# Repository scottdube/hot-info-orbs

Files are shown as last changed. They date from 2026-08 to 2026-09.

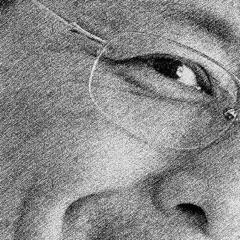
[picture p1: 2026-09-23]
test/fixtures/progressive.jpg

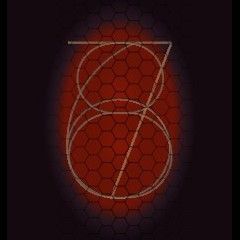
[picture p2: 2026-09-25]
images/ClockWidget/nixie.no-holes/colon_off.jpg

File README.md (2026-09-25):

# HoT Info Orbs

Five round 240×240 displays on one SPI bus, driven by an ESP32-S3 SuperMini, on
a custom carrier board. Clock, weather, stocks — and whatever else gets written.

Built as a club project, which shapes the whole thing: it is assembled by people
at a wide range of skill levels, so the build has to be hard to get wrong and
cheap to get into.

## Credit where it belongs

**This is a derivative of [Info Orbs by Brett Turner](https://github.com/brettdottech/info-orbs)**
— his project, his firmware, his idea. The upstream repository, its
[contributors](https://github.com/brettdottech/info-orbs/graphs/contributors),
and Brett's [assembly and flashing video](https://link.brett.tech/orbsYT) are
where this came from, and his boards can be
[bought as a dev kit](https://brett.tech/collections/electronics-projects/products/info-orbs-full-dev-kit)
if you want the original rather than our variant.

The firmware here is his, with local changes. The board is not: it is a new
design for a different microcontroller.

Licensed **AGPL-3.0**, inherited from upstream — see `LICENSE.txt`. Sharing a
built board with someone means they are entitled to the source, which is why
this repository is public.

## What is different here

| | Upstream | This |
|---|---|---|
| Microcontroller | ESP32 dev kit (30/38-pin) | **ESP32-S3 SuperMini** |
| Display supply | 3.3 V, off the module's regulator | **5 V, each module regulates its own** |
| API keys | compiled into `config.h`, shipped with live keys in the template | **`secrets.h`, gitignored, build fails without it** |
| Board | upstream's 2-layer design | **new carrier board, v1.1** |
| Firmware updates | USB cable every time | **over WiFi** — browser page or `pio run -e ota` |
| Boot splash | "Info Orbs by brett.tech", Brett's logo | **"HOT Info Orbs by HOT-Team"**, Yang's avatar for now; the Hands-On Tech hand (`images/hot-logo.jpg`) replaces it once Yang has this version |
| Settings | edit `config.h`, rebuild, reflash | **a page in the browser**: `http://<orb's IP>/settings` |
| Boot picture | fixed at build time | **upload your own** from the settings page |
| Weather | one Visual Crossing town | also **your own Tempest stations**, one page each (see SETUP step 10) |

**Upgrading a board flashed before 2026-09-23? Flash it once more over USB.**
The WiFi updates need a new flash layout (two firmware slots instead of one), and
only a USB flash writes that layout. Every update after that can go over WiFi:
open `http://<orb's IP>/update`, choose `.pio/build/esp32-s3-devkitc-1/firmware.bin`
and upload. The page also shows which commit is running. Set `OTA_PASSWORD` in
`secrets.h`, or anyone on your network can flash your orbs. Details in
[docs/SETUP.md](docs/SETUP.md#8-later-updates-no-cable-needed).

The 5 V change is the significant one. Upstream powers all five displays from
the ESP32 module's onboard regulator, which is why builders report the module
running at 82 °C with the radio off. The GC9A01 modules carry their own
regulators, so feeding them 5 V moves that load off the microcontroller
entirely. **Check the module you buy actually has one** — they vary, and it
looks like a small chip with capacitors either side on the back of the board.

## Getting started

**[docs/SETUP.md](docs/SETUP.md)** goes from an empty machine to a running orb,
assuming no PlatformIO experience, and ends in a troubleshooting table keyed by
the symptom you actually see.

The short version: copy **both** templates in `firmware/config/`, then build.

| Copy | To | Holds |
|---|---|---|
| `config.h.template` | `config.h` | preferences — timezone, units, tickers |
| `secrets.h.template` | `secrets.h` | your own API keys |

Both are gitignored; the templates are what's tracked. **The build refuses to
compile without both**, and refuses again if a key is left empty — deliberately,
because the alternative is a blank orb on the bench and no idea why.

Two free API keys are needed, about a minute each:
[Visual Crossing](https://www.visualcrossing.com/sign-up) for weather and
[TimeZoneDB](https://timezonedb.com/register) for DST changeovers. Register your
own — a shared key burns one free-tier quota and can be revoked out from under
everyone using it.

To have the orbs rotate Clock → Stocks → Weather on their own, set
`WIDGET_CYCLE_DELAY` in `config.h` to the number of seconds per page (15 works
well; 0 turns it off). Pressing a button restarts the countdown.

**After the first flash, most of `config.h` can be changed from a phone.** Open
`http://<orb's IP>/settings` to change the rotation time, tickers, weather
location and units, timezone, clock face and colors, night-dim hours,
upside-down mounting, and the start-up picture. The orbs restart to apply the
changes. The values in `config.h` become the defaults, and the page's reset button returns
to them. See [docs/SETUP.md](docs/SETUP.md#9-change-settings-from-a-browser).

## Hardware

The KiCad 10 project is in **[hardware/hot-info-orbs/](hardware/hot-info-orbs/)**.
Symbol and footprint libraries are project-local, so cloning and opening is all
that is required — nothing to install or copy into a global library.

**Board v1.1 — 10 boards ordered 2026-08-29**, tagged
[`v1.1-run1`](../../releases/tag/v1.1-run1). The exact gerbers sent to the fab
are committed at `hardware/hot-info-orbs/fab/`, and that file is never
regenerated: if a board comes back wrong, there has to be no question what was
sent. See [hardware/hot-info-orbs/fab/README.md](hardware/hot-info-orbs/fab/README.md)
for the order parameters and the drill-tool cross-check.

## Documentation

| | |
|---|---|
| [docs/SETUP.md](docs/SETUP.md) | empty machine to running orb |
| [docs/TRAPS.md](docs/TRAPS.md) | things that cost time once, so they cost it once |
| [docs/REQUIREMENTS.md](docs/REQUIREMENTS.md) | web control panel and OTA, with the traps that will bite whoever builds them |
| [docs/VARIANT-ESP32-S3-SUPERMINI.md](docs/VARIANT-ESP32-S3-SUPERMINI.md) | why the S3 SuperMini, including the arguments that reversed |
| [docs/ESPHOME-EVALUATION.md](docs/ESPHOME-EVALUATION.md) | why this is not an ESPHome project |

The variant and ESPHome documents keep the reasoning that changed rather than
only the conclusions. A decision with its argument attached can be revisited;
one without it gets re-litigated from scratch.

## Contributing

**Fork it and open a pull request.** Anyone can clone, build, fork and propose
changes — no permission needed for any of that, and a fork is yours to take in
whatever direction you like.

**Push access is by invitation**, and deliberately limited to a couple of
people. That is not gatekeeping the project, it is keeping the board files safe:
GitHub gives a personal repository no read-only collaborator tier, so adding
someone grants full write to everything including the KiCad files, which cannot
be merged if two people change them at once.

If you are building one of these and something is wrong or missing — a step in
the setup guide, a trap worth recording — [open an issue](../../issues) or send
a PR. Both are open to everybody, and a build that went sideways is worth
reporting even if you already worked around it: that is how the traps file gets
written.

## For collaborators

```bash
git pull --rebase     # before you start
# ...work...
git commit -am "what changed and why"
git push
```

`git config pull.rebase true` once, and a plain `git pull` does the right thing.

**KiCad files cannot be merged.** If two people edit `hot_info_orbs.kicad_pcb`,
git cannot reconcile them and somebody's work is lost. No tool fixes this, so it
is handled by saying so out loud: *"I've got the board"* / *"it's yours"*.
Everything else — firmware, docs, config — merges normally and needs no
ceremony.

Do not edit the KiCad project while it is open in KiCad, including with scripts.
KiCad holds its own copy in memory and writes it back on save, silently
discarding changes made underneath it. That has already cost a merge here once.

MegaLinter runs on every push and is configured **not** to commit anything back.
Upstream had it auto-committing fixes, which meant a bot pushed after every push
and rejected the next one — so "the remote has moved" stopped meaning "the other
person did something".

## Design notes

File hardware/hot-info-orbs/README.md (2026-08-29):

# HoT Info Orbs — KiCad project

ESP32-S3 SuperMini carrier for five GC9A01 displays. Original board by Yangmin
Shen, KiCad 10, received 2026-08-28.

## Libraries are project-local, on purpose

The custom symbols and footprints live in `lib/` and are wired up through
`sym-lib-table` and `fp-lib-table` using `${KIPRJMOD}`. **Do not move them into
your global KiCad libraries.** Clone the repo, open the project, and everything
resolves with no setup.

This is deliberate. Upstream's board (`PCBFiles+Schematics/Main PCB`) references
libraries named `A Local Libs` and `New folder` that exist only on its author's
machine — the footprints render because KiCad caches them inside the board file,
but nobody else can place a new instance or update one. Project-local tables
avoid that permanently.

| Nickname | Provides |
|---|---|
| `_AZDelivery components` | `GC9A01_TFT` symbol |
| `_ESP32 modules` | SuperMini symbol + footprint |
| `_Displays` | `GC9A01_PINS` footprint |
| `_Logos` | `Hot_Logo_5x5mm` footprint |

**`_Logos` was not in the zip.** It was recovered by extracting the embedded
footprint from `hot_info_orbs.kicad_pcb`, since KiCad caches full definitions in
the board file. It is byte-equivalent to what the board already places, but it
has not been round-tripped through the footprint editor — if it misbehaves, ask
Yang for the original.

`.kicad_prl` is deliberately not committed: it is per-user editor state
(open tabs, zoom, last-used layer) and only creates conflicts.

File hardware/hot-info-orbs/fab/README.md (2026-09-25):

# Fab package

## FIRST PRODUCTION RUN — v1.1

**ORDERED 2026-08-29 — 10 boards, JLCPCB.**

**`hot_info_orbs_v1.1_run1_gerbers.zip` is the package the first boards were
ordered from.** Generated 2026-08-29 from the board tagged `v1.1-run1`.

Do not regenerate this file to "refresh" it. If the board changes, the next run
gets its own zip and its own tag, and this one stays exactly as ordered — the
whole point is that when a board comes back, there is no question what was sent.

Verified before generating: ERC 0, DRC 0 unconnected pads, 0 schematic parity
issues. One silkscreen-overlap warning on B.Silkscreen near U2, accepted as
cosmetic.

Drill tools cross-checked against the footprint count:

| Tool | Holes | |
|---|---:|---|
| 0.30 mm | 18 | vias |
| 0.80 mm | 2 | C1 |
| 1.00 mm | 53 | 5×7 display headers + 18 module pins |
| 1.10 mm | 12 | 3 buttons × 4 pads |
| | **85** | total |

The four Ø3.20 mm mounting holes are deliberately absent from the drill file —
they are `Edge.Cuts` circles the fab routes, not drills.

### Via geometry — RESOLVED, no issue

Earlier drafts flagged the 0.6 mm / 0.3 mm vias as a possible problem: a
0.150 mm annular ring against a "0.18 mm minimum annular ring" figure on
JLCPCB's capabilities page. **That was the wrong number.**

JLCPCB's order form states the rule as a *diameter* difference, not a ring:

> "Via diameter should be 0.1mm (0.15mm preferred) larger than Via hole size."

For a 0.3 mm hole that means a 0.4 mm diameter minimum, 0.45 mm preferred. These
vias are **0.6 mm on a 0.3 mm hole — 0.3 mm larger, three times the minimum and
twice the preferred.** Not close to a limit.

The same tooltip also settles cost:

> "No additional charge when the via hole ≥0.3mm, and via diameter ≥0.4mm."

0.3 mm hole and 0.6 mm diameter meet both conditions, so there is no via
surcharge on this order.

**Lesson worth keeping:** the capabilities page and the order form express the
same constraint differently, and the capabilities page's figures are not
internally consistent. When a number decides something, take it from the order
form.

## Order parameters

| | |
|---|---|
| Layers | 2 |
| Dimensions | 198.8 × 28.5 mm |
| Thickness | 1.6 mm |
| Min quantity | 5 (price per board drops steeply above that) |

Board exceeds 100 × 100 mm, so it does not fall in the cheapest tier.

## What the drill file should contain

Cross-check after any regeneration — the counts come from the footprints, so a
mismatch means something was added or lost:

| Tool | Holes | |
|---|---:|---|
| 0.30 mm | 21 | vias |
| 0.80 mm | 2 | C1 |
| 1.00 mm | 53 | 5×7 display headers + 18 SuperMini pins |
| 1.10 mm | 12 | 3 buttons × 4 pads |

**The four mounting holes are deliberately not in the drill file.** They are
Ø3.20 mm circles on `Edge.Cuts`, so the fab routes them as cutouts rather than
drilling them. If they ever appear in the drill file, somebody converted them to
a footprint and that changes how they are made.

## Verified before generating

ERC 0, DRC 0, 0 unconnected pads, 0 schematic parity issues.

## Design rules

Set 2026-08-28 from JLCPCB's published capabilities for standard 2-layer, 1 oz.
They were all `0.0` before, so DRC was checking nothing.

| Rule | Value |
|---|---|
| Min clearance | 0.10 mm |
| Min track width | 0.10 mm |
| Min through-hole | 0.15 mm |
| Min via diameter | 0.25 mm |
| Min annular width | **0.15 mm — see below** |
| Min copper-to-edge | 0.5 mm (JLC allows 0.2; the board already passes at 0.5) |

The board uses 0.2 and 0.35 mm tracks, so it has 2–3.5× margin on width.

### The annular ring number is the one to confirm

JLCPCB's capabilities page states a minimum annular ring of 0.18 mm,
"recommended 0.25 mm or above". This board's 17 smaller vias are 0.6 mm pad on a
0.3 mm drill, giving **0.150 mm** — under that figure.

Two reasons it is set to 0.15 here rather than 0.18:

1. **The quoted 0.18 is not internally consistent** with the rest of that page,
   which also gives a 0.15 mm minimum drill and a 0.25 mm minimum via diameter —
   0.15 + 2×0.18 would be 0.51 mm, not 0.25. The figures appear to span
   different capability tiers, so 0.18 should not be treated as settled.
2. **0.6/0.3 is KiCad's default via** and is what an enormous number of boards
   are fabricated with at JLC every day.

**Enlarging the vias was tried and made things worse.** Taking the 17 vias to
0.8 mm gave the required ring but produced 24 clearance violations, because the
larger pads crowd neighboring copper. Fixing it properly means moving traces —
real layout work on someone else's board, not a settings change.

**If certainty is wanted before ordering, ask JLC directly whether 0.6/0.3 vias
are acceptable on a standard 2-layer order.** Nothing else on the board is close
to a limit.

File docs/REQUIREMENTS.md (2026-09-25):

# Feature requirements

Requirements for this build beyond what upstream provides. Each says what it
must do and *why*, because the why is what survives when the how changes.

Context: this is built as a learning project by people at a range of skill
levels, several of whom will be new to embedded development. **Complexity and
cost are constraints, not preferences.** A feature that adds a build step, a
part, or a failure mode has to earn it.

---

## R1 — Web control panel

**Settings must be changeable without rebuilding or reflashing the firmware.**

Today every preference lives in `config.h` and is compiled in. Changing a stock
ticker, a weather location, or a timezone means opening VS Code, editing a C
header, rebuilding, and connecting a USB cable. For someone who assembled the
hardware but does not write code, that is a wall.

**Must:**
- Serve a configuration page from the device over the local network
- Cover the settings people actually change: timezone, weather location, units,
  ticker list, clock face, and the scheduled dim hours (see the note below —
  this is not brightness control)
- Persist to NVS so settings survive a reboot and a firmware update
- Be reachable without special software — a browser on a phone is enough

**Should:**
- Show the device's current state: WiFi signal, uptime, last successful API call
- Allow API keys to be entered here rather than compiled in

**Interaction with the secrets work — read this before implementing.** Keys are
currently compile-time constants in a gitignored `secrets.h`, guarded so an
empty key fails the build. Moving keys to runtime NVS storage weakens that
guarantee: a device can then be flashed and running with no keys at all, failing
silently at the first API call. If keys move to the panel, the panel must show
their status plainly — set, unset, or last call failed — because the build-time
error that currently catches this goes away.

**There is no brightness control, and there cannot be on this hardware.** The
7-pin GC9A01 modules do not break out the backlight pin — BL is tied on at the
module, so the backlight runs at full output whenever the board is powered.
Upstream's "dimming" is a firmware effect: during the configured hours it
scales every color's R, G and B down before drawing (`Utils::rgb565dim`,
level 128 of 255 by default), so the display *looks* dimmer. It draws exactly the same
current.

So the panel can expose the dim *hours*, and must not offer a brightness slider.
A slider that does nothing is worse than no slider — someone will report the
orbs as too bright at night and be told to adjust a control that was never
connected to anything.

Real dimming needs different hardware: a display module that exposes BL, wired
to a PWM-capable GPIO. Worth weighing when the next batch of modules is chosen,
because it also cuts the dominant continuous load — the backlight, not the
radio, is what makes these boards warm.

**Screens off (added 2026-09-24).** A second schedule, separate from the dim
hours, sends the GC9A01's display-off and sleep-in commands (0x28, 0x10) to all
five panels. Each schedule has its own switch, so an orb can dim in the evening
and go off at bedtime, or use only one. Where the two overlap, off wins. The
HOT meeting that day asked for it, and the controller datasheet lists the
commands. Scott's first look in daylight: "looks pretty good". **Checked by
eye 2026-09-25:** the backlight stays on, so the panels glow with no content,
"not black by any stretch". Dim hours also checked and work. That fits the
LEDPWM result below: the LED runs off VCC on the module, not the controller.
So this "blanks the panels"; it does not turn the backlight off, and it
probably still draws full backlight current. **Not yet measured:** the
current draw.

**The controller does have backlight control; whether our module uses it is
untested (found 2026-09-25).** The GalaxyCore GC9A01 datasheet (V1.0
Preliminary), chapter 6 "Command", lists everything raised at the HOT
meeting: 10h/11h sleep in/out, 12h partial, 13h normal, 20h/21h inversion,
28h/29h display off/on. There is no separate power-down or deep-standby
command; Sleep In (10h) is the lowest-power state ("DC/DC converter is
stopped, Internal oscillator is stopped, and panel scanning is stopped").
Display Off (28h) only blanks the output, "no change of contents of frame
memory". Section 5.10.3, though, has an **LEDPWM output pin** meant to drive
an external LED driver, with Write Display Brightness (51h, DBV 0-255 = PWM
duty) and Write CTRL Display (53h, bits BCTRL, DD, BL, where BL = 0 means
"completely turn off backlight circuit"). That only works if the module
maker routed LEDPWM to the backlight. On the 7-pin modules the backlight
appears to run straight off VCC, but nobody has tested it. **Test:** send 53h
with BL = 0, and separately 53h = 0x24 plus 51h = 0x00, then look in a dark
room. If the backlight goes out, both real screens-off and real dimming become
possible on this hardware, and the "no brightness control" rule above changes.

**Result 2026-09-25: not wired.** Scott sent each command to all five panels
through a temporary `/bltest` route: BL = 0 ("off"), 53h = 0x24 with 51h at
0x00, 0x80 and 0xFF. None changed the backlight; only the restart did
anything. A panel whose backlight hung off LEDPWM would have gone dark at "off"
and at 0%, whatever the room light, so this settles it for these 7-pin modules:
the "no brightness control" rule stands, and real dimming still needs a module
that brings out BL. The route was removed once answered.

**What real screens-off would take (written 2026-09-25, not built).** No
command can darken these modules (above), so turning the backlight off means
cutting power to the displays. Nothing here has been built or measured on a
prototype, so treat it as a design to try.

*The load.* The displays run on **5 V**, each through its own onboard
regulator. The whole orb measures 342 mA at 5 V, so the display share is less
than that. A switch rated about 1 A leaves margin for the surge at turn-on.

*The switch.* It goes on the **5 V feed to the displays only**, high side.
Two ways to build it:

| | Parts | Notes |
|---|---|---|
| Discrete | P-channel MOSFET (e.g. AO3401A) in the 5 V line, 10 kΩ gate to 5 V; N-channel MOSFET (e.g. 2N7002) pulling that gate to ground; 10 kΩ from the 2N7002 gate to 3.3 V | The 2N7002 is needed because a 3.3 V pin cannot turn off a P-FET whose source is at 5 V. With the pull-up on the 2N7002, the displays are **on** by default, during boot and on firmware that knows nothing about the switch. The firmware drives the pin low to turn them off. |
| Load-switch chip | One IC rated to 5.5 V with a logic-level enable and controlled turn-on (TI TPS22918 is one; check the datasheet before choosing) | One part instead of three, and it ramps on gently. That matters because the ESP32's regulator is fed from the same 5 V line, and a hard switch-on dip could reset it. Needs a pull-up on the enable pin for the same displays-on default. |

*The pin.* The firmware already uses GPIO 1, 2 and 4–15. The vendor pinout
lists 16, 17, 18 and 21 as broken out and safe to use, but nobody has checked
them on the board we have. Look on the back pads before designing around one.
Avoid the strapping pins (0, 3, 45, 46). GPIO 14 is taken: it's the dummy
chip-select that TFT_eSPI still toggles. GPIO 15 is taken too: it's the
activity-light output (`BUSY_PIN`).

*Firmware, in order:*
1. **Off:** stop SPI, then drive MOSI, SCLK, DC, RST and all five CS lines
   **low**, then switch the power off. If those lines stay high, current leaks
   into the unpowered display chips through their input pins. That half-powers
   them and can make the backlight glow faintly, which defeats the point.
2. **On:** switch the power on, wait for the module regulators (start with
   50 ms and measure), restart SPI, re-initialize all five panels (power loss
   wipes the controller), then redraw everything. The existing screens-off
   schedule and 60-second button wake stay as they are; only what "off" does
   changes.

*Checks once built:* the orb's current at 5 V with screens off against on
(the saving we'd be buying); a meter on one module's VCC while off, which
should read about 0 V (a volt or two means a line is still high); and a
dark-room look.

*Rejected:*
- Switching the ground side. A logic-level N-FET is simpler to drive, but
  with ground cut, the modules find ground through the signal lines.
- Pulsing the supply rapidly on and off (PWM) to dim. It resets the display
  controller every cycle.
- The controller's LEDPWM pin. It isn't wired on these modules (tested above).

Dimming for real would need the LED switched on its own, which means modifying
each module. A look at the back of one would show whether there's a transistor
or pad to tap.

*Cost against the project's constraints:* three small parts or one IC, one
pin, and firmware sequencing. Worth it on a new carrier board. As a fix for
one existing orb, it's a lot of work.

**Security floor:** the panel holds WiFi credentials and API keys. It needs at
minimum a password, and it must never display stored secrets back in plaintext.
An unauthenticated page on the LAN that reveals WiFi credentials is not
acceptable, however friendly the network.

**Upstream already built this — found 2026-09-23.** `upstream/dev` (not
`main`, which this fork is based on; 571 commits apart) has
`firmware/src/core/configmanager/ConfigManager.*`: a settings page on
WiFiManager, stored in NVS via `Preferences`, with sections, an "advanced"
toggle and i18n. Per-widget settings register themselves; MainHelper.cpp
covers timezone, language, widget cycle delay, NTP server, orb rotation, and dim
hours. Measured by building `upstream/dev` against our S3 board and
partitions.csv: **1,712,081 bytes, 87.1% of one OTA slot**, no OTA code yet. So it
fits. Two conflicts with decisions here: it offers a `tftBrightness` setting,
which does nothing on these displays (see above), and its key handling has to
be reconciled with the `secrets.h` split.

**Status 2026-09-23: partly implemented — our own page, not upstream's.**
`http://<orb>/settings` covers rotation time, tickers, weather location,
units and screen mode, timezone, 12/24 h, AM/PM, starting clock face, clock
and shadow colors, night-dim hours, upside-down mounting, and an uploadable
boot picture. It saves to NVS and restarts. It has no brightness control.
It uses the same password as `/update`, and holds no secrets.
Tested from a phone on 2026-09-23: a 310×372 transparent PNG went through the
page's crop-and-shrink and arrived as a 16.7 KB baseline 240×240 JPEG, which the
orb stored and serves back. Not yet checked by eye on the displays.
Design and reasons: `docs/superpowers/specs/2026-09-23-web-settings-design.md`.
Tempest support (built 2026-09-24, merged to main 2026-09-25) adds Tempest station IDs and labels to the
page, each with its last fetch result (✔/✖, age, duration, error): the
per-source status the note above asks for. The Tempest token is deliberately
**not** on the page; it stays in `secrets.h`.
Not done yet: API keys on the page (needs the per-key status above first),
last-API-call status, and enabling/disabling widgets. WiFi signal, access
point and channel were added 2026-09-25, along with roaming (below). Flash is
87.0% of a slot, and the stop line is 92%.

**WiFi roaming (added 2026-09-25).** An orb moved across a building kept its
far access point: 341 ms average ping and 5% loss, while the router answered
in 3 ms, and every 96 KB Tempest reply arrived cut short. Restarting didn't
help. The ESP32's default connect takes the first AP it hears, not the
strongest, and it never moves until the link dies. Now it scans every channel
and joins the strongest at connect. While connected, it checks 20 s after
joining and every 2 minutes after that. If the signal is below -65 dBm, it
scans in the background and moves to an AP at least 8 dB stronger on the same
network. The margin keeps two similar APs from trading the orb back and forth.
If the new AP doesn't take it within 20 s, it rejoins by network name.
Decision logic: `firmware/src/core/wifi/RoamPolicy.h`, tested on the host.
Rejected: the router steering clients (UniFi "lock to AP" is a per-device
setting someone has to know to change, and not every owner runs UniFi), and
802.11k/v/r roaming (it needs router support and ESP-IDF config this build
doesn't expose).

## R2 — Over-the-air firmware updates

**Firmware updates must not require a USB cable.**

**Status 2026-09-23: implemented and tested on the SuperMini.** USB flash of the
new layout, then a browser-style multipart upload to `/update` by IP: 11 s
upload, back on the network 14 s later. otadata read back over USB afterwards:
highest sequence 2 → running `app1`, state `VALID`, i.e. the new image reached
WiFi and confirmed itself. Not yet exercised: `pio run -e ota` (espota), a
password, an interrupted upload, and an actual rollback.
`firmware/src/core/ota/OtaUpdater.*`, browser upload at `/update` plus
ArduinoOTA (`pio run -e ota -t upload`). Partition table reworked to two
1.875 MB slots (app at 83.4%) with the filesystem cut to 128 KB. A new image is
confirmed only after it reaches WiFi and starts listening for the next update,
using the core's `verifyRollbackLater()` hook; the prebuilt bootloader has
rollback enabled. Version shows on the boot screen and the update page. Still
open: the *Should* — devices do not check for updates themselves.

The orbs sit on a desk or shelf, often in a case. Fixing a bug currently means
retrieving the device, opening it if necessary, finding a data-capable USB
cable, and running a toolchain the owner may not have installed. In practice
that means fixes do not reach people.

**Must:**
- Accept a firmware image over the network and apply it
- Fall back safely on a failed or interrupted update — a half-written image
  must not brick the device
- Report the running firmware version somewhere visible

**Should:**
- Check for updates rather than requiring a push to each device

**Constraint worth checking early:** the current build occupies 77.2% of a 2 MB
app partition. Conventional OTA wants two app partitions so the old image
survives until the new one is verified. Two 2 MB partitions do not fit in 4 MB
alongside NVS and SPIFFS. **The partition table in `partitions.csv` will need
reworking, and that is a bigger change than it sounds** — it is worth confirming
the layout before building against the current one.

## Prior art

[JoeAWagner/orbital-orbs](https://github.com/JoeAWagner/orbital-orbs) — Info
Orbs firmware with a web control panel and OTA updates, written for the ESP32-S3
variant. Both requirements here, already implemented by someone else. Read it
before writing anything: it may be adoptable directly, and where it is not, it
will still show where the partition and NVS problems actually bite.

## Open question — ESPHome

Whether these requirements are better met by reimplementing on ESPHome rather
than extending the Arduino firmware. ESPHome provides OTA, a web server, and
`secrets.yaml` natively rather than as features to build. Evaluated separately;
see `docs/ESPHOME-EVALUATION.md`.

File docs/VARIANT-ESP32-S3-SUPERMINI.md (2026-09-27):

# Variant: ESP32-S3 SuperMini

Status: **REOPENED 2026-08-27.** Declined earlier the same day on cost and
complexity, then reopened at Yang's request. The power objection that drove the
original decline now looks resolvable — see [Reopened](#reopened) at the end.
The earlier decision record is kept below rather than deleted, because the
reasoning that reversed is the useful part. This records what the
switch would actually cost, so the decision is made against facts rather than
against how small the board looks.

Date: 2026-08-27

---

## The question

Replace the 30-pin ESP32 devkit with an ESP32-S3 SuperMini. Does it have enough
pins, and what does the change drag along with it?

**Short answer: pins are not the problem. The carrier board is.**

---

## 1. Pin budget — it fits, barely

Counted from `firmware/config/config.h.template`, not estimated:

| Function | Pins | Notes |
|---|---:|---|
| SPI MOSI + SCLK | 2 | `TFT_MISO` is `-1`; displays are write-only |
| Display DC + RST | 2 | shared across all five |
| Per-screen chip select | 5 | one per display, the unavoidable cost of 5 panels on one bus |
| Buttons | 3 | |
| **Hard requirement** | **12** | |

Two more are soft. `BUSY_PIN` is a real output (`Widget.cpp:7`) but only drives an
activity indicator and can be dropped. `TFT_CS` appears solely in a
`Serial.println` in `ScreenManager.cpp:28` — very likely reclaimable, but confirm
TFT_eSPI isn't consuming it internally before counting on that.

**Against the candidates:**

| Board | Usable GPIO | Verdict |
|---|---|---|
| ESP32-C3 SuperMini | ~11 | **Does not fit.** Short before the optional pins. |
| ESP32-S3 SuperMini | 32 broken out; conservative "safe" set is IO1, IO2, IO4–8, IO15–18, IO21 = **exactly 12** | Fits, with zero margin on the safe set |

The safe set landing on exactly 12 is worth sitting with. It works, but any
future addition — a rotary encoder, a light sensor, an I²C bus — means reasoning
about strapping and boot-state pins rather than picking a free one.

**Unverified:** the S3 SuperMini pin classification above is from vendor
documentation, not from the board on the shelf. The specific AITRIP unit's flash
size and whether it carries PSRAM are **not confirmed**. Both must be read off
the actual module before any footprint is drawn.

## 2. Retracting the flash-size argument

An earlier claim that the S3's 4MB flash relieves the current squeeze **is
wrong**, and the correction matters because it removes one of the two upsides.

`partitions.csv` already maps a 4MB device:

```
app0,     app,  ota_0,   0x10000, 0x200000     <- 2MB app partition
spiffs,   data, spiffs,  0x210000,0x1E0000
```

The build reports 77.2% of `0x200000`. That is a **partition layout** constraint,
not a chip constraint. The classic board already has 4MB. An S3 SuperMini with
4MB therefore gives nothing here — and if the app partition needs to grow, that
can be done on the existing hardware by editing this file, no board change.

What genuinely remains on the S3 side: native USB (less fiddly flashing, no
BOOT-button dance), more GPIO headroom in principle, and physical size.

## 3. The carrier board — reassessed for 2-layer

**Updated 2026-08-27: two-layer boards are available.** This reverses most of
what this section originally argued. Recorded rather than deleted, because the
reversal is the useful part.

### What the original argument was

Read from `PCBFiles+Schematics/Main PCB/info_orbs.kicad_pro` and `.kicad_pcb`:

- Upstream's board is **2-layer**, track width defaults `[0.0, 0.2, 0.6]` mm
- In-house milling is **single-sided, no plated vias, 0.4 mm floor**

So upstream's board could not be milled here, and any board — SuperMini or
devkit — meant a single-sided redesign with jumpers. That made the SuperMini's
PCB cost look nearly free, since a redesign was happening anyway, and it made
ordering look attractive purely to escape the one-layer fan-out problem.

### What changes with 2 layers on the table

Every one of those premises drops:

| | Was (single-sided milled) | Now (2-layer ordered) |
|---|---|---|
| Five CS lines crossing a shared bus | jumper exercise, real routing risk | trivial, vias handle it |
| Min track / clearance | 0.4 mm floor | ~0.15 mm |
| Upstream's existing board | unusable | **usable as-is, or as a starting point** |
| Turnaround | hours | weeks |

**The important consequence: upstream's PCB becomes an asset instead of a dead
end.** For the classic devkit it can be ordered as drawn — zero PCB work. For
the SuperMini, the display and button sections of the existing KiCad project are
reusable; only the module footprint and its fan-out need redrawing.

### Which means the SuperMini's cost went back up

Not to "from scratch", but no longer to "free". Honestly stated:

- **Classic devkit, ordered:** no PCB work at all. Send upstream's Gerbers.
- **SuperMini, ordered:** new module footprint, re-layout of the module area and
  its fan-out, then a full verification pass. Days, not weeks — but not zero,
  and it is work that buys size and native USB rather than function.

The single-sided constraint was doing a lot of the arguing in favor of the
SuperMini. With it gone, the case rests on what it was always really about:
physical size and nicer flashing.

### The new cost is schedule

Ordered boards run weeks, not hours. That is the constraint to plan around now —
and it argues for settling the pin map on flying leads first, because a mistake
discovered after ordering costs another full turnaround.

## 4. Constraints on the carrier

**Applies only if this is milled in-house.** For an ordered 2-layer board the
drill-snapping and annular-ring gates below are irrelevant — the fab plates the
holes and stock KiCad footprints are fine. Kept because the milled path is still
open, and because the socket-pad trap is easy to carry into the wrong context.

Values traced to source, not quoted from memory:

| Constraint | Value | Source |
|---|---|---|
| Annular ring minimum | **0.25 mm**, checked *after* drill snapping | `pcbmill/constants.py:45`, `toollib.py:156` |
| Owned drill bits | 0.032″ / 0.0465″ / 0.0625″ / 0.125″ (0.813 / 1.181 / 1.588 / 3.175 mm) | `pcbmill/toollib.py:24-31` |
| Drill snapping | to **nearest** owned bit, not up | `toollib.py:128-138` |

Consequences for this board specifically:

- **Socket rows need 1.78 mm pads, not KiCad's stock 1.70 mm.** The stock
  `PinSocket_1x15_P2.54mm_Vertical` clears the 0.25 mm gate by about 9 microns.
  That is not margin. If the SuperMini is socketed rather than soldered down,
  this applies to every pin in both rows.
- **Machined-pin (turned) sockets, or direct-solder the module.** Never stamped
  female headers — a defective one cost a full day in this shop and mimicked a
  dead flash chip perfectly.
**True on any board, milled or ordered:**

- **Antenna keepout** at the SuperMini's antenna end. Non-negotiable, and easy
  to forget on a board this small where every mm is contested.
- **Bulk cap near the module supply pin** — 220 µF electrolytic plus 0.1 µF
  ceramic, ceramic closest. Five displays plus WiFi transmit bursts is exactly
  the load that browns out a module fed by a long trace.
- **Flash/PSRAM pin keepouts must be re-derived for the S3.** The familiar
  "GPIO6–11 are the flash bus" rule is an **ESP32-classic** fact and does not
  transfer. Whichever pins this variant reserves need NPTH mechanical holes —
  hole, no pad — so the pins pass through touching nothing.

## 5. Mounting — unanswered, and it blocks layout

**How does the board physically mount inside the orbs assembly?** Standoffs,
panel screws, or floating on the display connectors? This is not yet known, and
a board has reached Gerber export in this shop with no mounting holes because
nobody asked.

On the mill, mounting holes are free — same op, same G54. Retrofitting means
hand-drilling a soldered, masked board next to a pour, with no registration.
Decide before placing the first component. Default is M3 drilled 3.175 mm, NPTH,
with a ~6.5 mm keepout and center ≥ 3.2 mm from the board edge.

## 6. Power — the regulator is the real constraint

> **Superseded for the current build (noted 2026-09-25).** The displays now
> run on **5 V**, each through its own onboard regulator, so the SuperMini's
> regulator carries only the ESP32 (see `docs/features.html`: 342 mA / 1.71 W
> for the whole orb at 5 V, measured). The netlist analysis below describes
> the upstream wiring, and it is kept for the reasoning. Its load figures are
> estimates that the measurement replaces.

**Correction:** an earlier draft of this section said the displays run off 5 V.
They do not. The netlist is explicit — display connector pin 7 is
`Net-(U1-3.3v)` and pin 6 is GND. All five displays hang off the **module's
onboard 3.3 V regulator**, which makes the regulator comparison decisive rather
than incidental.

| | DevKit V1 (DOIT) | S3 SuperMini |
|---|---|---|
| Regulator | AMS1117-3.3, SOT-223 | ME6211-series, SOT-23-5 |
| Datasheet max | 1 A | 500 mA |
| Practical sustained | ~500-600 mA before thermal droop | 500 mA, and needs >=4.3 V in |

**The SuperMini has about half the headroom in a much smaller package.**

Estimated load, not measured: a GC9A01 1.28in module draws roughly 40-80 mA at
3.3 V with the backlight up. Five is 200-400 mA. The ESP32 itself spikes to
350-500 mA on WiFi transmit. Peak lands near **550-900 mA** — marginal on the
AMS1117, over the limit on a 500 mA part.

**Two things to verify physically, both quick:**

1. **Read the regulator marking** on one of the AITRIP boards. The ME6211 is
   documented on the C3 SuperMini and the S3 shares the SOT-23-5 footprint, but
   this specific board is unconfirmed.
2. **Measure one GC9A01 at full brightness** (part #70 is on the shelf) and
   multiply by five. That replaces the whole estimated range with a number.

### The design answer that removes the question

Give the display rail **its own 3.3 V regulator** on the carrier board, fed from
the 5 V input, rather than hanging five displays off the module's LDO. A 1 A LDO
is about a dollar, and the board then does not care which module is fitted.

Since a new board is being drawn anyway, this is likely correct regardless of
how the SuperMini decision goes — and it retires the single biggest electrical
risk in the variant.

## 7. Firmware port

Lower risk than the hardware, but not free:

- New PlatformIO environment (S3 target, not `esp32doit-devkit-v1`)
- Pin map rewrite in `config.h.template` — and the pin numbers become part of
  the variant's identity, so the two builds can no longer share one config
- TFT_eSPI on S3 needs its own verification pass; the GC9A01 driver is the same
  but the SPI peripheral is not
- `platformio.ini` currently declares `platform = espressif32` unpinned, which
  is a separate reproducibility question that a second board makes worse

## 8. Cost that is not technical

Upstream's assembly video, wiring diagram and dev kit all assume the classic
board. Anyone following those with a SuperMini in hand gets stuck. If more than
one person is building these, a board change means the written setup path in
`docs/SETUP.md` forks — or stops matching reality for half the builders.

---

## What is on the shelf

- **AITRIP Type-C SuperMini ESP32-S3** — InvenTree part #60, 4 on hand: 2 at
  B3-R6C3 (SLN), 2 at LRD. Recorded as spare stock, bought for the voice
  assistant and wrong for it. Flash/PSRAM variant **not verified**.
- Classic devkits: #62 (ESP-WROOM-32, 2 free at B3-R6C3) and #58 (38-pin CP2102,
  2 free). The current build BO-0016 allocates one of #62.

## Recommended sequence, if this proceeds

Ordered so the cheapest disqualifier runs first:

1. **Measure the 5 V draw** of five displays at full brightness. Five minutes,
   and it can end the discussion.
2. **Verify the actual module** — read the silk, confirm the flash/PSRAM variant
   and the true usable-GPIO set. "SuperMini" is not a specification.
3. **Port the firmware on flying leads.** Prove the S3 drives five GC9A01s
   before any copper is drawn. No PCB risk taken until this works.
4. **Lay out the carrier** as a modification of upstream's KiCad project, not
   from scratch — the display and button sections carry over.

Ordering runs weeks per turn, so steps 1-3 are not optional preliminaries. A pin
map error found after the boards arrive costs another full turnaround.

Steps 1–3 cost parts already on the shelf and no money. Step 4 is where the
commitment starts.

## Open questions

- How does the board mount in the assembly? (blocks layout — see §5)
- ~~Milled single-sided, or ordered 2-layer?~~ **Resolved 2026-08-27: 2 layers
  available.** See §3 for what that reversed.
- Does the variant replace the classic build or sit alongside it? That decides
  whether `config.h.template` forks or grows conditionals.
- Is the SuperMini socketed or soldered down? Socketing is friendlier to
  reflashing and rework but drags in the 1.78 mm pad requirement and doubles the
  height.

---

# Appendix: Is upstream's board poorly laid out?

Measured 2026-08-27 from `PCBFiles+Schematics/Main PCB/info_orbs.kicad_pcb`.
Every number here came from parsing that file, not from inspection by eye.

## What is on the board

| | |
|---|---|
| Footprints | 16 (3 are graphics with no pads) |
| Pads | 135, **all through-hole**, no SMD |
| Nets | 36 |
| Track segments | 277 — 155 on F.Cu, 122 on B.Cu |
| Copper length | 204 cm front, 38 cm back |
| Vias | 56, every one 0.6 mm pad / 0.3 mm drill |
| **Copper pours** | **zero** |

## Three findings that explain the 56 vias

**1. There is no ground plane.** Not on either layer. Every ground and power
connection is an individually routed trace. Ground touches 14 pads across the
board and is the highest-fanout net on it; a bottom-layer pour would absorb
nearly all of those with no vias at all. The 14-via net `Net-(J1-Pin_1)` is
ground, stitched across the board one hop at a time.

**2. The board carries TWO ESP32 module footprints, both fully wired.** `V1`
(`New folder:38 Pin Board`) and `V2` (`A Local Libs:38 Pin Board thin`) — 38
pads and 36 nets each, connected in parallel so either module variant can be
fitted. That is a deliberate choice, not an error, but it roughly doubles the
routing burden. Every shared bus net reaches seven pads instead of five: five
displays plus both module positions.

**3. The back layer is used for stubs, not for a strategy.** 204 cm of copper on
the front against 38 cm on the back, yet 56 vias to service that back layer.
122 back-layer segments carrying 38 cm total means the pattern is hop over an
obstacle and hop straight back.

Supporting evidence of hurry rather than intent: two *different* 38-pin board
footprints, a library named `New folder`, a footprint named `Untitled`, and no
power symbols in the schematic — the nets are auto-named `Net-(U1-3.3v)` and
`Net-(J1-Pin_1)` rather than `+3V3` and `GND`, which is *why* nothing could be
poured. You cannot pour to a net the schematic never named.

None of this makes the board wrong. It works, and hundreds of people have built
it. It was drawn for a fab house where vias are free and there is no reason to
count them.

## How many connections actually need the other side?

Tested rather than estimated: the netlist was built into a graph — one node per
pad, net connections as edges, each component's pin rows locked into their
physical order, routing under through-hole parts allowed — and checked for
planarity. A planar graph can be drawn with no edge crossings, which is the
graph-theory statement of "routable on one layer".

| Scenario | Net edges | Planar? | Crossings required |
|---|---:|---|---:|
| One module, nothing poured | 59 | **yes** | **0** |
| One module, GND poured | 49 | **yes** | **0** |
| One module, GND + 3V3 poured | 37 | **yes** | **0** |

**The circuit is inherently single-layer routable.** Upstream's 56 vias are a
property of their layout, not of this design. Drop the duplicate module
footprint, pour ground, and place the five display connectors in a row so the
shared bus runs along it, and the topology has no forced crossings at all.

### What this result does not prove

Planarity is about topology; it ignores geometry. Specifically:

- It assumes traces can be made as thin as needed. At the 0.4 mm milling floor
  they cannot.
- **It ignores that you cannot thread a trace between 0.1″ header pads.** The
  gap between 1.7 mm pads at 2.54 mm pitch is about 0.84 mm — too tight to
  isolate reliably on the mill. With 5×7-pin connectors, routing *around* rather
  than *between* is where real crossings will appear.
- Display placement is not actually free; the enclosure dictates where five orbs
  sit.

So the honest reading: **zero crossings are forced by the circuit, and whatever
crossings appear will be driven by clearance geometry, not topology.** That is a
much better starting position than 56 suggests, and it means a small number of
jumpers, not a stitched board.

## Consequence: a milled prototype looks feasible after all

This retracts the earlier claim in §3 that a single-layer version would be a
jumper exercise. It would not. A single-sided milled board with a ground pour
and a handful of jumpers is a realistic prototype path, which matters because
production is going to JLCPCB regardless — the mill only has to get a testable
board onto the bench, not produce the final article.

The remaining unknown is geometric, not topological, and the way to settle it is
to attempt the layout rather than to reason further about it.

---

# Appendix B: Attempting the layout — where geometry actually bites

The planarity result in Appendix A says zero crossings are forced by the
circuit. Planarity ignores geometry. This is what happens when the geometry is
put back in.

## The pinout is the whole problem

All five display connectors are identical 1x7 headers:

| Pin | Net | |
|---|---|---|
| 1 | IO18 — RST | shared by all five |
| **2** | **IO13 / IO33 / IO32 / IO25 / IO21** | **unique per display** |
| 3 | IO19 — DC | shared |
| 4 | IO17 — MOSI | shared |
| 5 | IO23 — SCLK | shared |
| 6 | GND | shared |
| 7 | 3V3 | shared |

**The one signal that differs per display sits at pin 2 — fenced in between two
shared bus lanes.** Every other pin can be served by a straight lane running the
length of the row. Pin 2 cannot, because each connector's pin 2 goes somewhere
different.

## The hard constraint, computed

Header pads are 1.70 mm on 2.54 mm pitch:

```
pad-to-pad gap    0.84 mm
one track needs   1.20 mm   (0.40 trace + 0.40 clearance each side)
tracks that fit   0
```

**Nothing routes between adjacent header pads at the milling floor.** Not one
track. Every connection either arrives from outside the pin column or does not
arrive.

## The layout that follows

Place the five connectors in a row, pin columns parallel, pins perpendicular to
the row. Then:

- **Pins 1, 3, 4, 5, 7 become straight horizontal lanes**, each at its own pin
  height, hopping connector to connector. No crossings, no detours.
- **Pin 6 (GND) disappears into the pour** and costs nothing.
- **Pin 2 is the exception.** Each CS line must reach a pad whose neighbors on
  both sides are occupied bus lanes.

A CS line heading for a distant connector must route around the intervening pin
columns — there is no path between the pads. Sending it above the row (past pin
1) into a clear channel works, and 4 such tracks need only 3.6 mm of channel,
which is nothing on a board this size. But coming back *down* to pin 2 means
crossing the pin-1 RST lane.

**That crossing is the irreducible cost, and it is one per CS line that has to
get past another connector.**

## The number

| Module placement | Jumpers |
|---|---:|
| Module at one end of the row | **4** |
| Module in the middle of the row | **3** |

With the module at the left, CS for the nearest display runs alongside the RST
lane without crossing it; the other four each cross once. Moving the module into
the middle of the row splits the fan-out in both directions and saves one.

Routing the RST lane above the CS channel instead does not help — then RST has
to come down to each pin 1 and crosses the CS tracks instead. The count is
symmetric because the topology is.

## Verdict

**Three or four jumper wires on a single-sided milled board.** Not 56, not
zero. That is an entirely reasonable prototype — a handful of short wire links
soldered on the copper face.

The path is open: mill a single-sided prototype in-house with a GND pour and
3–4 jumpers, prove the firmware and the pin map on real hardware, then send the
proper 2-layer design to JLCPCB for production where the jumpers become vias and
cost nothing.

## One trap to fix before milling

The stock 1x7 header footprint is **1.70 mm pads on a 1.00 mm drill**. Milled:

```
drill 1.00 snaps to nearest owned bit 1.181 (UP)
annulus = (1.70 - 1.181)/2 = 0.2595 mm
gate = 0.25 mm  ->  passes by 9.5 microns
```

It passes, with no margin worth the name — this is exactly the socket-row case
the shop guide flags. **Grow the header pads to 1.78 mm** before generating CAM,
which takes the annulus to 0.299 mm and a 49 µm margin. Same change applies to
all five display connectors and the module row if it is socketed.

Note this is a *milling* concern only. Sent to JLCPCB, the holes are plated and
the stock footprint is fine.

---

# Appendix C: HackerBox 0129 "Orbital" — someone already built this

Found 2026-08-27. HackerBoxes shipped a monthly kit that is this exact variant:
ESP32-S3 SuperMini, five GC9A01 modules, three tactile buttons, custom PCB.
Their own description: *"originally inspired by the very cool Info Orbs from
Brett Turner... employs a different microcontroller (ESP32-S3 vs ESP32) and thus
has a different PCB layout and different IO pin assignments."*

Sources: [product page](https://hackerboxes.com/collections/past-hackerboxes/products/hackerbox-0129-orbital),
[build guide](https://www.instructables.com/HackerBox-0129-Orbital/) (published
2026-07-29, 11 people report building it).

## What this hands us for free

**A working pin map for the S3, published:**

```c
#define TFT_MOSI 11
#define TFT_MISO -1
#define TFT_SCLK 12
#define TFT_CS   10
#define TFT_DC    9
#define TFT_RST  13
#define USE_HSPI_PORT

#define SCREEN_1_CS 4
#define SCREEN_2_CS 5
#define SCREEN_3_CS 6
#define SCREEN_4_CS 7
#define SCREEN_5_CS 8

#define BUTTON_OK    1
#define BUTTON_LEFT  2
#define BUTTON_RIGHT 3
```

**And the PlatformIO target:**

```ini
[env:esp32-s3-devkitc-1]
platform = espressif32
board = esp32-s3-devkitc-1
board_upload.flash_size = 4MB
```

Three things this settles that were open in §1 and §7:

1. **The firmware port is a config edit, not a project.** `config.h` pin
   defines plus a new env block. §7 estimated more work than that.
2. **13 GPIO, not 12.** They kept `TFT_CS` (pin 10) rather than reclaiming it,
   so the real budget is 13.
3. **My "exactly 12 safe pins" caution in §1 was over-conservative.** They use
   IO1 through IO13 contiguously, including IO3 and IO9-13 which the
   conservative classification lists as restricted. Those restrictions apply to
   variants with octal PSRAM; on this board they are usable in practice, and 11
   builders confirm it.

**Flash is confirmed 4MB** (`board_upload.flash_size = 4MB`), which supports §2:
no headroom gain over the classic board.

## What it does not fix

- **No regulator for the display rail.** The kit contents are PCB, five female
  1x7 headers, three buttons, one right-angle male header. No LDO, no bulk
  capacitor. Five displays hang directly off the SuperMini's onboard regulator,
  exactly the arrangement §6 flags as the electrical risk. It evidently works
  well enough to ship — but "works" here is untested against brownout under
  simultaneous WiFi transmit and full backlight.
- **It runs stock Info Orbs firmware**, so every configuration and secrets
  problem this repo just fixed is still present in theirs.
- **The PCB is not published as source.** The Instructable attaches an `.ino`
  demo sketch and a 3-D printed stand `.stl`. No Gerbers, no KiCad project. It
  cannot be forked, only bought — and it is a past box, sold while supplies
  last.

## One thing worth checking on their pin map

**GPIO3 is a strapping pin on the ESP32-S3** (JTAG signal source select), and
they assign it to `BUTTON_RIGHT`. Info Orbs wires buttons to VCC with
`INPUT_PULLDOWN`, so a button held down during reset drives a strapping pin
high at boot. Likely harmless in the default eFuse configuration, but it is the
kind of thing that produces an intermittent "sometimes won't boot" that nobody
connects to a button. **If a pin map is being drawn fresh anyway, move that
button off IO3.**

## Assessment: better as a starting point, not as a project

**Take from it:** the pin map, the PlatformIO target, and the empirical proof
that one SuperMini drives five GC9A01s. That is genuine de-risking and it costs
nothing.

**Do not take:** the power architecture. The dedicated display-rail LDO in §6
remains the right call, and their omission of it is not evidence against —
they were building to a kit price with no PCB revisions planned.

From a planning standpoint it is *worse*, not better: a discontinued monthly box
with an unpublished board, no maintenance path, and no way to fork the hardware.
Its value here is as a reference design that proves the electrical concept, not
as something to depend on.

## Appendix C.1: Field reports confirm the thermal problem

Builders in the Instructable comments report the SuperMini running hot. One
quantified it:

> "my ESP32 gets 'very' hot. Painful to touch. Close up thermal image shows
> 180 F." — wheagy1, on the HackerBox 0129 Instructable

**180 °F is 82 °C, not 180 °C.** Still a problem, and the qualifier in the same
comment is what makes it serious: *"I've only loaded the graphics test so far."*
**That temperature is with the radio off.**

Working back from a 57 °C rise over ambient, through a SOT-23-5 LDO dropping
5 V to 3.3 V:

| θ_JA assumption | Dissipation | Implied current |
|---|---|---|
| 250 °C/W (still air) | 229 mW | 135 mA |
| 150 °C/W (on copper) | 381 mW | 224 mA |

Now add the radio, which Info Orbs uses constantly:

| WiFi TX burst | Total current | Junction temp |
|---|---|---|
| +150 mA | 374 mA | ~120 °C |
| +250 mA | 474 mA | ~146 °C |
| +350 mA | 574 mA | **~171 °C — past thermal shutdown** |

LDO thermal shutdown is typically 150–165 °C, and the ME6211-class part is
rated 500 mA absolute maximum. **The margin is already spent on the graphics
demo.**

This is field confirmation of §6 rather than new analysis, and it settles the
open question there: the dedicated display-rail LDO is not a nicety, and
HackerBoxes' omission of one is a defect in their board, not a demonstration
that it is unnecessary.

### Two corrections from the same comment thread

**GPIO count returns to 12.** A builder traced the PCB with a multimeter and
lists **GP10 as "Unused?"** — so `TFT_CS 10` appears in HackerBoxes' config but
is not physically connected. Appendix C revised the budget up to 13 on the
strength of their config file; that was wrong. `TFT_CS` is vestigial, as §1
originally suspected, and the requirement is 12.

**A maintained fork exists.** [JoeAWagner/orbital-orbs](https://github.com/JoeAWagner/orbital-orbs)
— Info Orbs for the ESP32-S3 with a web control panel and OTA updates. That is
the runtime-configuration approach considered and deferred during the secrets
work, already implemented by someone else. Worth reading before building it.

**Sourcing caveat:** reply threads on that Instructable are login-gated. Only
top-level comments were read directly; reports of additional heat complaints are
secondhand.

---

# Decision: declined

**2026-08-27 — staying with the ESP32 dev kit. The SuperMini variant is closed.**

The evaluation answered its own question. Pins were never the constraint, and
the two things that would have justified the switch did not survive contact with
the measurements:

- **Flash headroom was a mirage.** `partitions.csv` already maps 4 MB with a
  2 MB app partition, and the SuperMini is also 4 MB (§2).
- **Power got worse, not better.** The dev kit's AMS1117-3.3 is 1 A in a SOT-223
  with a real thermal tab; the SuperMini carries a 500 mA part in SOT-23-5.
  Field reports put the SuperMini at 82 °C *with the radio off* (§C.1).

What remained was physical size and native USB — real, but not worth what they
cost here.

**The deciding factor was complexity and cost, not the electronics.** This is
built as a learning project by people at a range of skill levels. The dev-kit
path needs no new carrier board, no added regulator, no new footprint, and no
divergence from the upstream assembly documentation that builders will follow.
The SuperMini path needs all four before anyone sees a working orb.

On the dev kit the power problem largely goes away: roughly twice the current
headroom in a package that can shed the heat. The dedicated display-rail
regulator discussed in §6 becomes an option rather than a requirement — still
worth doing on any new board, no longer load-bearing.

**Consequences:**

- InvenTree BO-0016 already allocates a classic dev kit (#62), so the parts
  claim is unchanged and needs no correction.
- The four AITRIP SuperMini boards stay as general spare stock.
- The two-layer JLCPCB question stands on its own merits — upstream's board can
  be ordered as drawn (§3), which is now the zero-work option.
- Everything measured here about the displays, the pinout, the planarity result
  and the 3–4 jumper count applies unchanged to a dev-kit board.

**What would reopen this:** a display rail with its own regulator making the
module's LDO irrelevant, plus a reason to care about size. Neither is true today.

---

# Reopened

**2026-08-27, later the same day.** Yang asked to move to the S3 SuperMini. The
decision to decline was made on cost and complexity, not on a technical
blocker — and the technical objection that carried the most weight now looks
answerable.

## What changed: the power problem may cost nothing to fix

The decline rested on the SuperMini's 500 mA SOT-23-5 regulator against the dev
kit's 1 A AMS1117, with field reports at 82 °C. That analysis assumed the five
displays draw from the module's 3.3 V rail, as upstream wires them.

They may not have to. The GC9A01 clone modules being considered appear to carry
**their own onboard regulator** — a 3-terminal part with input and output
capacitors is visible on the module PCB. If confirmed, then:

- The displays run from a **5 V bus** taken off the module's 5 V pin
- Each module drops 5 V to 3.3 V itself, spreading roughly 0.1 W across five
  packages instead of concentrating ~0.5 W in one
- The SuperMini's regulator carries only the ESP32 — the ~52 °C case
- **No added regulator, no added parts, no carrier-board complexity**

That removes the objection without spending the cost and complexity budget that
closed this the first time.

## What must be confirmed before committing

Three things, all on one module, none of them analysis:

1. **Is there really a regulator?** Feed 5 V to VCC and measure at the
   3-terminal part's output. ~3.3 V means yes. Read its marking (`662K` would
   be an XC6206-3.3).
2. **What do the resistors on the logic lines do?** If they are series damping,
   3.3 V logic passes fine. If any form a divider sized for 5 V logic, 3.3 V in
   becomes roughly 2.2 V at a controller wanting about 2.3 V — marginal, and
   marginal fails intermittently rather than cleanly. Measure resistance from
   SDA to GND and from SDA to the controller side.
3. **Measure the actual current** at full brightness, and multiply by five.

**"GC9A01 clone from AliExpress" is not a specification.** Inventory already
records one generic module (#418, HiLetgo) as 3.3 V only, and another (#70,
Waveshare) as 3.3/5 V with an 8-pin interface including BL. Same controller,
same form factor, different power design. Buy one before buying five.

## Proposed pin map

HackerBoxes' published map spends all of IO1–10 — the S3's ADC1 pins — leaving
nothing analog for expansion, and puts a button on IO3, a strapping pin. Moving
the bus up frees ADC1 entirely:

| Function | Pins |
|---|---|
| MOSI / SCLK | 11, 12 |
| DC / RST | 13, 14 |
| Screen CS ×5 | 15, 16, 17, 18, 21 |
| Buttons | 4, 5, 6 |
| **Free, all ADC1** | **1, 2, 7, 8, 9, 10** |

Avoids IO0/3/45/46 (strapping), IO19/20 (native USB), IO43/44 (UART), IO48
(onboard LED). Costs compatibility with HackerBoxes' board, which is irrelevant
for a board drawn here.

## What still stands from the decline

- **Flash headroom is still a mirage.** Both boards are 4 MB with a 2 MB app
  partition (§2). Nothing gained.
- **A carrier board is still needed**, with a new module footprint and fan-out
  re-layout. Ordering 2-layer from JLCPCB makes that tractable (§3).
- **The 3–4 jumper analysis and the planarity result are unaffected** — they
  describe the display fan-out, not the module.

## Note on the missing BL pin

The 7-pin clone has no backlight pin; the backlight is hardwired on. Upstream
is the same: the display symbol in Brett's `info_orbs.kicad_sch` has seven pins
(RST CS DC SDA SCL GND VCC), and his firmware never defines `TFT_BL`. So no
Info Orbs build has ever controlled the backlight. Since the
backlight is the dominant *continuous* load, a module exposing BL would allow
PWM dimming — real brightness control instead of the color desaturation the
firmware currently uses, and a direct cut in the thermal load. Worth weighing
when choosing which clone to buy, on either board.

---

## 2026-09-24: where the flash goes (measured, `tempest` build)

Image 1,730,737 bytes, 88.0% of one 1,966,080-byte OTA slot (stop line 92%, so
~80 KB of working headroom). Free heap after a Tempest fetch is ~210 KB, so
**RAM is not the constraint. Flash is.** Having no PSRAM in the build only
forced streaming the Tempest reply, which works.

Largest symbols (`xtensa-esp32s3-elf-nm --size-sort`) are all framework:
newlib printf/scanf (~57 KB across 6 variants), mbedTLS handshakes, mDNS,
lwIP, WiFi. The largest app symbols are `SettingsPage::handlePost` (3.5 KB) and
`renderForm` (3.1 KB). Trimming our own features buys kilobytes, not hundreds of
them. **The ceiling is 4 MB of in-package flash split into two OTA slots**,
and only a module with more flash moves it. A board change still means a new
carrier footprint and fan-out (§3).

**Correction 2026-09-25: the symbol sort above missed a quarter of the
image.** Files embedded with `board_build.embed_files` show up to `nm` as
unsized `_binary_*` symbols, so a size sort never lists them. Their
`_binary_*_size` symbols add up to **440,199 bytes, 22% of a slot** (image
1,749,229 bytes, 89.0%):

| Embedded | Bytes | Where it's used |
|---|---:|---|
| Nixie clock JPGs (12) | 152,276 | nixie clock face |
| DSEG14ModernBold.ttf | 71,756 | only the AM/PM text on the clock |
| RobotoRegular.ttf | 62,420 | all ordinary text |
| logo.jpg | 35,557 | boot screen |
| Weather icons, dark + light (14) | 64,058 | weather page |
| DSEG7ModernBold.ttf | 22,524 | clock digits |
| FinalFrontier.ttf | 19,812 | **nothing**: loadable, but no widget selects it |
| Custom clock JPGs (12) | 11,796 | custom clock face |

Levers, cheapest first (measured unless marked):
- **Drop FinalFrontier:** −19,812 bytes, no visible change. It removes a
  font that upstream's config could select.
- **Re-save the JPGs at quality 80** (PIL, baseline, optimized): 263,687 to
  198,672 bytes, **−65 KB**. Most of it is the nixie digits (−45 KB) and the
  logo (−12.5 KB). The icons barely shrink; they're already at about q80. Needs an eye
  check on the panels, and re-encoding a JPG loses a little each time, so
  use the originals if they can be found.
- **Subset DSEG14 to the glyphs AM/PM needs:** estimated −60 KB or more,
  not measured. Needs fonttools. DSEG is OFL; check its Reserved Font Name
  terms before shipping a modified copy.
- **Subset Roboto to Latin-1 plus the symbols we draw:** estimated −20 to
  −35 KB, not measured. Risk: any glyph outside the subset (a ticker or a
  weather description with other characters) draws as nothing.

**Done 2026-09-25, first two levers:** FinalFrontier left out, and the nixie
digits and logo re-saved at q80 (the custom clock JPGs are 983-byte
placeholders and gained nothing, so they were left alone). The image went
from 1,749,229 to 1,671,701 bytes (**89.0% to 85.0%**, −77.5 KB). Nixie
look: Scott's check pending.

Together the four levers come to roughly 150–180 KB, about 89% down to 80%. By contrast, the
framework (printf, mbedTLS, lwIP, WiFi) is precompiled and not ours to trim.

## 2026-09-24: a more capable variant on the same carrier?

**PSRAM on our unit: 2 MB, present and working. Measured 2026-09-24.** The
earlier "no PSRAM" was an assertion, never a measurement. A throwaway build
adding `-DBOARD_HAS_PSRAM` to `build_flags` (nothing else) was flashed to the
orb, and the settings page reported `psramFound=1`, `ESP.getPsramSize()`
2,094,607 bytes, 2,053,695 free while running, and flash 4,194,304 bytes. So
the chip is the 4 MB flash + 2 MB quad PSRAM part. The PSRAM is quad, on
in-package pins (CS 26, CLK 30), so it takes no GPIO from the carrier. The
core's init fails soft (a `log_w` warning, then it carries on) if the PSRAM
is missing, so the flag would be safe on a board without it.

- **Flash cost: +3,592 bytes** (1,730,737 to 1,734,329, 88.2%).
- **Not enabled in the committed build.** The orb went straight back to the
  soaking build. Turning it on changes where the heap puts allocations over
  4 KB, and WiFi/lwIP buffers can move into PSRAM too. That needs its own soak.
- `esp_chip_info()`'s `CHIP_FEATURE_EMB_PSRAM` read **0** on this chip, even
  with the PSRAM working. That bit is no use for detecting it on IDF 4.4.
- It adds RAM, not flash. The 4 MB flash / two-slot ceiling is unchanged.

**No SuperMini with more flash was found.** Every "N8R8"/"N16R8" result was a
DevKitC or Waveshare Zero layout. AliExpress was not browsed (it blocks
fetches), so that is the one open lead.

Candidates, from datasheets and KiCad footprints. Prices fetched live
2026-09-24 unless marked.

| | Flash / PSRAM | Footprint vs our 2×9 @ 15.24 mm | GPIO | Price |
|---|---|---|---|---|
| **ESP32-S3 SuperMini (Basic, today)** | 4 MB / 2 MB quad | ours | 12 used | $4.25, what Scott last paid (not a live price) |
| Seeed XIAO ESP32S3 | 8 MB / 8 MB octal | 2×7, **same 15.24 mm rows**, pin 1 differs | 11 edge | $7.49, in stock |
| XIAO ESP32S3 Plus | 16 MB / 8 MB octal | same edge + 9 SMD-only back pads | 11 edge + 8 back | $7.99, in stock |
| UM TinyS3 | 8 MB / 8 MB quad | 11+12, same 15.24 mm rows | 17 | $20 at Adafruit, not stocked; UM's own store not checked |
| Waveshare ESP32-S3-Pico | 16 MB / 2 MB | 40-pin Pico layout | 27 | $8.99–9.99 |

None is a drop-in: the power pins and SPI pins sit in different places.

**Ways to keep one carrier:**

1. **Adapter board (preferred).** The carrier keeps the SuperMini 2×9 in
   machined-pin sockets (§4 already recommends them). The advanced module is
   soldered to a small adapter whose 2×9 pins present the SuperMini pinout. The
   carrier is unchanged, the adapter is a small 2-layer board, and the firmware
   gets a per-module pin map in `config.h`. Costs: a second small board, and
   extra height.
2. **Overlapping second footprint on the carrier.** Row spacing matches the
   XIAO, but each display net would need a pad on both footprints, in the
   module area, and Appendix B found nothing routes between header pads. Rejected for
   the milled 2-layer board.
3. **Separate carrier.** Clean, but two boards to maintain.

**The XIAO is one GPIO short (11 edge vs 12 hard).** The likely way out is
`TFT_RST -1`, where TFT_eSPI resets the panels by command and the RST line is
held high on the board. Unmeasured on these panels; test it before an adapter
depends on it.

## 2026-09-27: more app room on the same 4 MB, before any hardware

Revisited the Advanced module because flash is the limit. **A partition layout
that nobody had costed yet gets most of what a bigger module would.** The two
OTA slots each hold a full copy of the app, embedded pictures and fonts included,
so half the chip is always a spare copy.

**Factory recovery layout.** Keep one full app slot, and put a small recovery app
in `factory` whose only job is WiFi plus an upload page. An update restarts into
recovery, which writes the main slot and boots it.

**Measured:** a minimal recovery app (WiFi + `WebServer` + `Update`, same
unpinned `espressif32` platform as the firmware) builds to **716,256 bytes**.

| | Today (two OTA slots) | Factory + one slot |
|---|---|---|
| factory | none | 0x10000, 0xD0000 (832 KB, 116 KB margin over the 716 KB measured) |
| app slot | 2 × 0x1E0000 (1,966,080 B) | 1 × 0x2F0000 at 0xE0000 (**3,080,192 B**) |
| spiffs, coredump | unchanged | unchanged |
| current image (1,671,701 B) | 85.0% | **54.3%** |

About +1.1 MB for the app, 1.57× today's slot, with no module change, no
adapter board and no new pin map.

What it costs:
- **A bad update lands in recovery, not the old firmware.** The orb stays
  reachable over WiFi and can take another upload, but the displays show nothing
  until it does (unless recovery also drives one panel, which adds TFT_eSPI).
  Today a bad update rolls back to the previous version.
- **Updates are two hops:** the app restarts into recovery, then the upload goes
  to recovery. `pio run -e ota` and the `/update` page both change.
- The app can't update itself (`esp_ota_get_next_update_partition` has nowhere
  else to write), so the recovery app is load-bearing. It has to be small,
  boring and rarely changed.
- **One more USB flash** per orb for the new partition table, as with the OTA
  change.

Not measured: rollback into `factory` on this bootloader (the A/B rollback was
tested 2026-09-23; the factory path was not), and how long the extra restart and WiFi reconnect add to an update.

**Still true for the Advanced module (XIAO ESP32S3 Plus, 16 MB):** it also
brings 8 MB octal PSRAM and keeps A/B rollback, but it needs the adapter board, a
JLCPCB turnaround, a second pin map and the untested `TFT_RST -1`. Worth it for a
feature that needs PSRAM or several MB of assets; not needed for flash alone
until the factory layout's 3 MB slot fills.

A web search on 2026-09-27 turned up no SuperMini-footprint board with 8 or
16 MB. AliExpress is still unbrowsed.

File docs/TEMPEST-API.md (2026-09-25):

# Tempest (WeatherFlow) API — measured, 2026-09-24

Measured from the laptop against an account that owns two stations (SLN and LRD). The
token came from Home Assistant's `weatherflow_cloud` integration. It is never
committed; the firmware reads it from `secrets.h`.

Station IDs, names and coordinates are **not recorded here**: this repo is
public, and a station name plus coordinates is a home address. They go in each
orb's own settings.

`GET https://swd.weatherflow.com/swd/rest/stations?token=…` lists them.

## The forecast call

`GET https://swd.weatherflow.com/swd/rest/better_forecast?station_id=<id>&units_temp=f&token=…`
(`units_temp=c` for metric)

- **~96 KB per reply** (95–97 KB for both stations). About 100 KB of that is
  `forecast.hourly`: 231 entries nobody on the orbs needs. `http.getString()`,
  which the Visual Crossing code uses, would hold all of it in RAM. The
  build does not enable PSRAM (the chip has 2 MB, measured 2026-09-24; see
  VARIANT-ESP32-S3-SUPERMINI.md), so the reply has to be **streamed through an
  ArduinoJson filter**.
- **Field order in the raw stream:** `current_conditions` at byte 1,
  `forecast.daily` at byte 906, `forecast.hourly` at byte 3,584, and `station`
  and `status` in the last ~450 bytes. Everything the page needs is in the
  first ~3.6 KB.
- `current_conditions`: `conditions` (text, e.g. "Partly Cloudy"), `icon`,
  `air_temperature`, `feels_like`, `relative_humidity`, `wind_avg`, and more.
- `forecast.daily[*]` also carries `sunrise` and `sunset` as epoch seconds
  (ints). Measured 2026-09-24; the keys are `air_temp_high`, `air_temp_low`,
  `conditions`, `day_num`, `day_start_local`, `icon`, `month_num`,
  `precip_icon`, `precip_probability`, `precip_type`, `sunrise` and `sunset`.
  **There is no moon phase anywhere in the reply**, in `current_conditions` or
  `daily`, so it has to be computed on the orb (it is date arithmetic) or come
  from another source.
- `forecast.daily`: 10 days. **`daily[0]` is today** (`day_num` = today's
  date): `conditions`, `icon`, `air_temp_high`, `air_temp_low`. Visual
  Crossing's `days[0]` is also today, and the page shows `days[1..3]`.

## Icons seen

Both stations, one day, current + daily + hourly: `clear-day`, `clear-night`,
`cloudy`, `partly-cloudy-day`, `partly-cloudy-night`, `possibly-rainy-day`,
`possibly-rainy-night`, `rainy`, `possibly-thunderstorm-day`,
`possibly-thunderstorm-night`, `thunderstorm`.

The orb's icon set (`WeatherWidget::drawWeatherIcon`) knows
`partly-cloudy-day/night`, `clear-day/night`, `snow`, `rain`,
`fog`/`wind`/`cloudy`. Tempest's names need a translation table. The names
Tempest documents but that were not seen on this day (`foggy`, `windy`,
`sleet`, `snow`, `possibly-snow-*`, `possibly-sleet-*`) are unmeasured.

## On the orb (measured 2026-09-24, branch `tempest`)

Streamed with `useHTTP10(true)` and the filter from `TempestParse.h`:

- **The filter keeps 744 bytes** of a real ~96 KB reply (measured on the host
  against a saved reply).
- **Fetch time**, connect to parse, as reported on the settings page for
  two stations: 1.4 to 2.7 s. The loop is blocked for that long, the same way as
  for the Visual Crossing fetch.
- **Free heap after a fetch:** 210 to 211 KB.
- **Flash:** 1,728,589 bytes, 87.9% of a slot, with the token compiled in.
  Without it: 1,710,645 bytes. That is +960 over main: +460 for the source
  split and +500 for the two extra string fields in the settings struct.
- **The start-up fetch runs before the clock has synced**, so the settings page
  gives the fetch's age from `millis()`, not a clock time. Measured: the first
  version stamped both fetches `00:00`.

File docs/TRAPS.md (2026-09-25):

# Traps

Things that cost time once. Each entry says what broke and what proved it.

## A privacy grep that names what it looks for is the leak

2026-09-24, branch `tempest`. The plan's check that a test fixture held no
real station data was a grep whose pattern listed the real station IDs and
name fragments. So the check itself put them in a public repo. It was caught
after the push and removed from the branch history.

Keep private values out of anything committed, including commands that
search for them. Read them from the git-ignored `config.h` at run time, and
grep the staged diff before pushing, not after.

## `config_helper.h` is force-included into C files, not just C++

`platformio.ini` passes `-include "firmware/config/config_helper.h"`, so that
header lands in **every** translation unit — including plain C from vendored
libraries (`tjpgd.c`, `sd_diskio_crc.c`). Anything C++-only in it breaks the
build inside someone else's library, with an error pointing at our header.

Cost a build cycle when a `static_assert` guarding the API keys was added
unguarded. Now gated on `defined(__cplusplus)`.

**Anything added to that header must be valid C**, or be inside a
`#if defined(__cplusplus)` block.

## One build failure can mask another

The first `pio run` died at `bootloader.bin` on a missing `intelhex` module.
That looked like the only problem — but it aborted the build *before* the C
library files compiled, hiding the `static_assert` breakage entirely. The
second failure only appeared once the first was fixed.

**A build that fails early has not verified the code it never reached.** Fix
and re-run before concluding anything compiles.

## `clang -fsyntax-only` is not a substitute for a real `pio run`

The header guards were checked with `clang -fsyntax-only` on a C++ translation
unit. All three states passed. The real build then failed, because the check
never compiled a C file and never touched the vendored libraries.

Useful for fast preprocessor logic checks. Not evidence the firmware builds.

## PlatformIO's Python environment is replaced by VS Code updates

A VS Code update can rebuild `~/.platformio/penv` from scratch, and the fresh
environment came up missing `intelhex`, a dependency of esptool 4.11. Symptom
is a machine that built ESP32 firmware fine for months suddenly failing at
`bootloader.bin`.

Fix: `~/.platformio/penv/bin/python -m pip install intelhex`

Diagnostic that settles it fast: `stat -f '%SB' ~/.platformio/penv` — if the
creation date is today, the environment is new, and prior successes were on a
different one.

## `git add -A` near an open KiCad project commits its session state

KiCad writes `~<project>.kicad_*.lck` lock files while a project is open, and
the editor keeps a `.history/` sidecar that is **its own git repository**. A
blanket `git add -A` swept all four into a commit here — the lock files as
ordinary files, and `.history` as a gitlink pointing at a repo that exists only
on one machine. A clone would get a broken submodule reference.

Now covered by `.gitignore` (`~*.lck`, `**/.history/`, `*-backups/`,
`*.kicad_prl`). The general lesson stands regardless: **check `git status`
before `git add -A` in a directory someone has open in a GUI tool.**

Related: the presence of `~*.lck` is also the reliable test for whether KiCad
has a project open, which matters because writing to a project directory while
KiCad holds it corrupts state.

## Strapping pins keep turning up on user-facing connections

Two independent boards for this project both route an MCU strapping pin
somewhere a user can drive it:

**Upstream, GPIO12 on the `U1` expansion header.** `U1` is a 1x6 sensor
breakout carrying 5V, 3V3, GND, GPIO34, GPIO35, GPIO12. GPIO34/35 are a good
choice — input-only and on ADC1, which still works while WiFi is active. GPIO12
is not: it is MTDI, the strapping pin that selects flash voltage at boot. Held
high at reset on a 3.3V-flash module, the board may not boot. It is also ADC2,
so it cannot do analog while the radio is up. The header offers 3V3 two pins
away from it.

**HackerBox 0129, GPIO3 as `BUTTON_RIGHT`.** GPIO3 is an ESP32-S3 strapping pin
(JTAG source select), and Info Orbs wires buttons to VCC with `INPUT_PULLDOWN` —
so a button held during reset drives it high.

Both produce the same failure signature: **an intermittent no-boot that nobody
connects to a button or a sensor lead**, because it only happens when something
is held at the moment of reset.

**When drawing a pin map, check the strapping list for that exact part first.**
It differs between ESP32 variants — classic is GPIO0/2/5/12/15, S3 is
GPIO0/3/45/46 — so a map ported between them silently changes which pins are
hazardous.

## Changing the build contract breaks CI silently

The secrets split made `secrets.h` a required file and added a guard that
rejects an unfilled key. Both are deliberate. But `.github/workflows/platformio.yml`
created only `config.h`, so every CI build failed from that commit onward —
with our own `#error`, on a repo nobody was watching the checks on.

It went unnoticed for several commits because the repo was private and nothing
surfaces a red check unless you look. **If you change what the build requires,
change CI in the same commit.** The build guard is the point; CI has to satisfy
it like any other builder.

CI now writes both files and injects `CI_BUILD_ONLY` placeholder keys — it
compiles, it never calls the APIs. Note the injection is done in Python rather
than `sed`: the matrix runs ubuntu, macos and windows, and `sed -i` differs
between GNU and BSD and does not exist in the default Windows shell.

## ESP32-S3 native USB: a serial monitor that connects, says nothing, and drops

Symptom on a freshly ported S3 build: `pio device monitor` attaches, prints no
output, then loops `Disconnected (read failed: [Errno 6] Device not configured)`
/ `Reconnecting... Connected!` forever.

It looks exactly like a boot loop and is not. **Check whether the board is
actually up before diagnosing the firmware** — 20 pings with 0% loss settles it
in ten seconds, and that is what happened here: the firmware was running fine
and on the network the whole time.

The cause is that Arduino's `Serial` defaults to **UART0 on GPIO43/44**, not to
the USB port, so nothing services a CDC endpoint and macOS keeps losing it.

**The obvious fix makes it worse on this board. Tried and reverted 2026-09-10:**

```ini
; DO NOT USE on the SuperMini without testing on hardware first
-D ARDUINO_USB_MODE=1
-D ARDUINO_USB_CDC_ON_BOOT=1
```

With those set, the *application* takes ownership of the USB peripheral instead
of leaving it to the ROM. It then fails to enumerate, and the board disappears
from the host completely — no `/dev/cu.usbmodem*`, nothing in
`system_profiler SPUSBDataType`. It still boots, still joins WiFi, still answers
pings. There is simply no port left to flash over.

Recovery is manual bootloader entry: hold BOOT while plugging the USB cable in,
then reflash. Which is unpleasant on a board whose BOOT and RST silkscreen is
unreadable — the recovery attempt is also how you find out which button is which.

**The diagnostic that keeps this cheap:** a board that has vanished from USB but
answers pings is not broken, and the firmware is not the thing to investigate.
Ping first. Both times this came up, the firmware was running correctly and only
the host link was in question.

Serial output on this board therefore needs a different route — UART0 on
GPIO43/44 with an external adapter — or you wait for displays, which report the
same failures visually.
The classic ESP32 does not need this — it has a separate USB-serial chip, so
`Serial` reaches the host without any build flag. This is specific to parts
where the MCU provides USB itself, and it is easy to miss when porting because
nothing about the build fails.

After enabling CDC the first upload may need the manual bootloader entry (hold
BOOT, tap RST, release BOOT), because the USB device presents differently.

## `info-orbs.local` resolves but curl to it stalls — use the IP (2026-09-23)

Measured from the MacBook right after the first OTA-layout flash: `dns-sd -G v4
info-orbs.local` answered at once with 192.168.30.208, but `curl
http://info-orbs.local/update` did not answer in a 3 s timeout for over a
minute, while `curl http://192.168.30.208/update` returned 200 first try. The cause is
not established. Whether a browser has the same problem was not tested. When
the name stalls, test the IP before concluding the orb or its web server is
down. The orbs show the IP when they connect.

**Re-measured 2026-09-24:** the same again. The name resolves at once, and
`curl http://info-orbs.local/settings` times out at 5 s, twice. On the SLN
network, use **`http://info-orb-sln.internal/settings`** instead. That is the
router's DNS name for the orb, not something the firmware sets: 200 in 0.19 s,
forward and reverse both point at 192.168.30.208. Another orb or another
network will not have it.

## `__DATE__`/`__TIME__` do not date the image (2026-09-23)

The OTA page first printed `built __DATE__ __TIME__` from `OtaUpdater.cpp`. After
a change to `main.cpp` only, the orb reported the *previous* build's time,
because that file had not recompiled. That is a version report that lies. Fixed with
`tools/build_id.py`, which writes the git commit into a generated
`firmware/include/build_id.h`. The ELF SHA-256 in the app descriptor was
checked as an alternative: this build leaves it zeroed.

## A failed `pio run -e ota -t upload` reboots the orb — and the next try hits the reboot (2026-09-23)

Measured: from the MacBook at 192.168.1.203, espota to the orb at 192.168.30.208
failed twice with `No response from device`. Each time the orb's port 80 then
refused connections for ~10–20 s and came back on the old firmware. That is by
design, not a crash: the invitation reaches the orb and fires `onStart`, the
orb cannot open the data connection back to the laptop, and `onError` restarts
it after 3 s (`OtaUpdater.cpp`). A `curl` upload fired straight after landed in
that reboot and was refused, which reads as "the orb is down".

espota needs the orb to connect **back** to the laptop; the browser/curl path
needs only laptop → orb. Across subnets (here .1.x → .30.x, TTL 63) only the
second was shown to work: `curl -F "firmware=@.pio/build/ota/firmware.bin"
http://<ip>/update` → `Update OK` in 11 s. Why the connect-back fails (routing,
firewall, macOS application firewall) was not established. After a failed
espota, wait for `/update` to answer 200 before trying anything else.

## Finding the orb on 192.168.30.x, and a URL that "doesn't work" (2026-09-23)

- **Several other devices on 192.168.30.x answer `/update` with a bare "200
  OK".** A port-80 sweep for `/update` does not find the orb; check that
  `/settings` contains "Running 1.1.0".
- **A trailing `.` pasted after the URL** (`…/settings.`) stops the page loading
  by itself. Rule it out first when someone says the page "doesn't work".
- **An orb that has gone completely dark on the network may simply be
  unplugged.** On 2026-09-23 it was an accidental unplug, not firmware. Ask
  before debugging. A 4 h watch at 30 s intervals afterwards (480 checks, 20:25–00:26) saw no drop.

## A `native` test env gets built by a bare `pio run` — and cannot compile the firmware (2026-09-24)

The web-settings merge added `[env:native]` for host unit tests. CI runs a bare
`pio run`, which builds **every** env, so it tried to compile `firmware/src`
for the host: `'Arduino.h' file not found`. It failed on all three OSes from
983c037 until the fix. Locally everything was green, because every local command
named its env (`-e esp32-s3-devkitc-1`, `-e ota`, `pio test -e native`).

Fix: `default_envs = esp32-s3-devkitc-1, ota` under `[platformio]`, plus an
explicit `pio test -e native` step in CI. This is the "change the build
contract, change CI in the same commit" trap above, a second time. **Before a
merge, run the exact CI command (`pio run`, no `-e`) locally.**

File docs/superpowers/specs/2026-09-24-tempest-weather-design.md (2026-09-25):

# Tempest weather — design

**Date:** 2026-09-24 · **Branch:** `tempest` · **Status:** approved in chat, spec awaiting review

## What and why

Scott has a WeatherFlow Tempest station at each site (SLN and LRD). He wants
the orbs to show weather from those stations, **one weather page per station**
in the rotation. Today the orbs show a single Visual Crossing page for one
town.

Decisions made in chat, with the options rejected:

| Question | Chosen | Rejected |
|---|---|---|
| How do two sites appear? | Two full weather pages in the rotation: clock → SLN → LRD → stocks | One combined page (loses the 3-day forecast); one page alternating sites (only one site per pass) |
| What does a Tempest page show? | The same five orbs as today, fed from Tempest | Swapping orb 1 for a wind/rain/humidity readout. That is a later round; a new screen design now would cost flash and an eye check |
| How is it built? | A: a data-source split inside `WeatherWidget`, one widget instance per station | B: a separate Tempest widget (duplicates the drawing code: flash, and every fix made twice). C: read the stations through Home Assistant (ties the orbs to Scott's HA; the club couldn't use it) |
| Where does it live? | Branch `tempest`, built so Tempest is **compiled out** unless `TEMPEST_TOKEN` is defined | Mixing it into main now. Whether `tempest` ever merges is Scott's later call; compiled-out means a merge would cost Yang's build nothing |

Measured API facts are in `docs/TEMPEST-API.md`. Station IDs are not in this
repo, because it is public and a station amounts to a home address.

## Global constraints

- Flash stays **below 92%** of a 1,966,080-byte slot (87.0% before this work).
  Measure after every task that adds code.
- The SuperMini has **no PSRAM**. Never hold a whole Tempest reply (~96 KB) in
  RAM.
- The Tempest token lives only in `firmware/config/secrets.h` (git-ignored),
  never on the settings page and never in the repo. The page must never show
  it.
- With `TEMPEST_TOKEN` undefined, the build and the orb behave **exactly** as
  on main.
- Every settings-page state keeps a glyph as well as a color (✖/✔/⚠).

## Design

### 1. Data source split

`WeatherWidget` keeps all its drawing code and the five-orb layout. Fetching
and parsing move behind an interface:

```cpp
class WeatherSource {
  public:
    virtual ~WeatherSource() = default;
    virtual bool fetch(WeatherDataModel &model) = 0; // true = model filled
};
```

- `VisualCrossingSource`: today's `getWeatherData()` body moved as is, with
  its URL built from Settings as now.
- `TempestSource(stationId, label)`, only when `TEMPEST_TOKEN` is defined.
- `WeatherWidget(ScreenManager&, WeatherSource*)`. The existing
  `update()`/retry/10-minute logic calls `m_source->fetch(model)`.

### 2. Tempest fetch

`GET https://swd.weatherflow.com/swd/rest/better_forecast?station_id=<id>&units_temp=<f|c>&token=<TEMPEST_TOKEN>`
(`c` when Settings `wxmetric`).

- `http.useHTTP10(true)`, so the reply is not chunked, then
  `deserializeJson(doc, http.getStream(), DeserializationOption::Filter(filter))`.
  The filter keeps only:
  - `current_conditions.conditions`, `.icon` and `.air_temperature`
  - `forecast.daily[*].icon`, `.air_temp_high` and `.air_temp_low`
  - the whole of `hourly` is discarded as it streams
- Model mapping:
  - city name = the station's **label** (e.g. "SLN")
  - text = `current_conditions.conditions`
  - icon = the translated `current_conditions.icon`
  - temperature = `air_temperature`
  - today high/low = `daily[0]`
  - the 3 forecast days = `daily[1..3]`
- Failure (HTTP error, parse error, fewer than 4 days): return false and keep
  the previous data. The existing retry and 10-minute cycle apply unchanged.
- The label shows on orb 1 before the first successful fetch.

### 3. Icon translation

Pure function `tempestIcon(const std::string&) -> std::string`, std-only in a
header so the native tests cover it:

| Tempest | Orb icon |
|---|---|
| `clear-day`, `clear-night`, `cloudy`, `partly-cloudy-day`, `partly-cloudy-night` | unchanged |
| `rainy`, `possibly-rainy-day/night`, `thunderstorm`, `possibly-thunderstorm-day/night` | `rain` (the orb has no storm icon) |
| `snow`, `sleet`, `possibly-snow-day/night`, `possibly-sleet-day/night` | `snow` |
| `foggy` | `fog` |
| `windy` | `wind` |
| anything else | `cloudy` |

### 4. Settings

New `SettingsValues` fields: `tstn1`, `tlbl1`, `tstn2`, `tlbl2`.
- Station ID: 0 = unused. The page accepts 1 to 9 digits. `sv::parseInt` stops
  at 6 characters, so a new `sv::parseStationId` handles this.
- Label: `normalizeText`, 1–8 characters.
- Defaults come from new optional `config.h` macros `TEMPEST_STATION_1`,
  `TEMPEST_LABEL_1`, `TEMPEST_STATION_2` and `TEMPEST_LABEL_2`, and fall back
  to 0 and "".
- NVS keys are added without a schema bump; an absent key falls back to its
  default, as it does for every existing key.
- **Settings page:** a "Tempest stations" section appears only when
  `TEMPEST_TOKEN` is compiled in. Two rows, each a station ID and a label, with
  the config.h default shown as a hint. The token itself is never shown or
  mentioned beyond "token set in secrets.h".
- Each station row also shows its **last fetch result**, e.g. "✔ 14:32, 4.1 s"
  or "✖ 14:32 HTTP 401". `TempestSource` keeps the time, duration and
  code of its last attempt. There is no serial on the SuperMini, so this is the
  only way to see a fetch fail without looking at the orbs.

### 5. Start-up wiring (`main.cpp`)

When `TEMPEST_TOKEN` is defined and at least one station ID is non-zero, add
one `WeatherWidget(new TempestSource(id, label))` per set station, in order 1
then 2, where the single Visual Crossing widget is added today. Otherwise add
the Visual Crossing widget as now.

## Testing

- **Native (`pio test -e native`):**
  - `tempestIcon` against every row of the table.
  - `parseStationId` edge cases.
  - The filter and parse step against a **made-up** sample reply in
    `test/fixtures/tempest_sample.json`, shaped like the real one (including a
    long `hourly` array) but with no real station, name or coordinates.
  - The parse test needs ArduinoJson on the native env (it is header-only).
- **On the orb, from the laptop:**
  - Both stations show "✔" as their last fetch result on the settings page.
  - Record the fetch duration the page reports: the 96 KB download blocks the loop.
  - Free heap before and after a fetch.
  - Flash percentage.
- **By eye (Scott):** SLN and LRD pages in the rotation, with correct labels,
  temperatures, icons and forecast.
- Build **without** `TEMPEST_TOKEN`: it must match main's flash size to within
  a few hundred bytes. That proves the feature compiles out.

## Out of scope

- A wind/rain/humidity/pressure/lightning readout: the next round, and it needs
  its own screen design.
- More than two stations.
- The local UDP broadcast from the hub, which only reaches the station on the
  same LAN.
- Putting the token on the page. It would make a password mandatory (see R1).

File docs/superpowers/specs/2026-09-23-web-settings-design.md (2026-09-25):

# Web settings page — design

**Status:** approved by Scott 2026-09-23. Implements R1 in `docs/REQUIREMENTS.md`
(partially — see Scope). Builds on the OTA web server merged the same day.

## Why our own page rather than upstream's

`upstream/dev` has a finished settings page (`ConfigManager`, 1.71 MB built for
our S3, fits). It was rejected for three reasons. It is unreleased contributor
work that never reached upstream `main`. Adopting it means moving this fork across 571
commits. And it offers a brightness control that cannot work on these
displays. This page covers only the settings in the table below and lives on
the server that OTA already runs.

## Scope

### v1 — on the page

| Setting | Key | Type / range | `config.h` default today | Read at |
|---|---|---|---|---|
| Rotation time, s per page | `cycle` | int, 0 (off) or 5–3600 | `WIDGET_CYCLE_DELAY` | `main.cpp:28` |
| Stock tickers | `tickers` | 1–5 symbols, comma-separated | `STOCK_TICKER_LIST` | `StockWidget.cpp:11` |
| Weather location | `wxloc` | text, 1–64 chars | `WEATHER_LOCATION` | `WeatherWidget.h:60` |
| Weather units | `wxmetric` | bool | `WEATHER_UNITS_METRIC` defined? | `WeatherWidget.h:61`, `GlobalTime.cpp:117` |
| Weather screen | `wxdark` | bool (dark / light) | `WEATHER_SCREEN_MODE` | `WeatherWidget.cpp:41` |
| Timezone | `tz` | text, IANA name, 1–48 chars | `TIMEZONE_API_LOCATION` | `GlobalTime.cpp:135` |
| 24-hour clock | `h24` | bool | `FORMAT_24_HOUR` | `GlobalTime.h:82`, `ClockWidget.cpp:50,93` |
| AM/PM indicator | `ampm` | bool | `SHOW_AM_PM_INDICATOR` | `ClockWidget.cpp:50` |
| Starting clock face | `face` | Normal / Nixie (Custom only if built with `USE_CLOCK_CUSTOM`) | `DEFAULT_CLOCK` | `ClockWidget.h:99` |
| Clock color | `clkcol` | RGB565 via color picker | `CLOCK_COLOR` | `ClockWidget.cpp:23,27,31,211` |
| Clock shadow color | `shdcol` | RGB565 via color picker | `CLOCK_SHADOW_COLOR` | `ClockWidget.cpp:43,168,185` |
| Night dim | `dim` | bool | `DIM_START_HOUR` defined? | `WidgetSet.cpp:96` |
| Dim start / end hour | `dimstart`, `dimend` | int 0–23, may wrap midnight | `DIM_START_HOUR`, `DIM_END_HOUR` | `WidgetSet.cpp:99–104` |
| Orbs upside down | `invert` | bool | `INVERTED_ORBS` | `ScreenManager.cpp:13,87` |
| Boot picture | file `/boot.jpg` | 240×240 baseline JPEG, ≤ 64 KB | embedded `images/logo.jpg` | `main.cpp:107` |

Night dim exposes **hours only**. The dim *level* stays at `DIM_BRIGHTNESS`
from `config.h`, or 128 (the template's commented value) when that is undefined. The page has no brightness control. Upstream's dimming
darkens colors. The backlight is hard-wired on (REQUIREMENTS R1).

### Later — needs restructuring first

- **API keys on the page.** It removes the build-time empty-key guard, so it
  first needs per-key status: set, unset, last call failed.
- **Second-hand ticks, language.** `#if` blocks select code at compile time
  (`ClockWidget.cpp:45`, `GlobalTime.h:15`).
- **Enabling and disabling widgets.** `main.cpp` includes and adds widgets under `#ifdef`.
- **Clock font, custom clock face upload, MQTT/Parqet/WebData widgets.** These
  are compile-time selections. A custom face is 12 images, about 200 KB at
  Nixie-digit size, which does not fit the 128 KB filesystem.

### Never on the page

The OTA password, and any stored secret displayed back. WiFi credentials stay with
WiFiManager's setup portal.

## Architecture

Three units, each usable without reading the others' internals.

**`Settings`** (`firmware/src/core/settings/Settings.{h,cpp}`) is the only code that
touches NVS. It uses the `Preferences` namespace `orbs`. It has typed
getters that fall back to the `config.h` value when a key is absent, so an orb
that never opened the page behaves exactly as today. It also has `save(values)` and
`factoryReset()`, which clears the namespace. A `schema` key (= 1) is written with every save,
so a later layout change can detect old data. Loaded once in `setup()` before
any widget is constructed.

**`SettingsValidation`** (`firmware/src/core/settings/SettingsValidation.h`) is
pure functions, with no Arduino types beyond `String`. For each field it either
normalizes the raw form value (trims, upper-cases tickers, collapses spaces) or
returns a message saying what is wrong. Kept separate so it can be unit-tested
on the host.

**`SettingsPage`** (`firmware/src/core/settings/SettingsPage.{h,cpp}`) holds HTTP
handlers registered on the `WebServer` that `OtaUpdater` owns. `OtaUpdater`
gains `WebServer &server()` and `bool authorized()` so that both pages share one
server and one password check rather than each binding port 80.

- `GET /settings` returns the form, filled with current values. Every field
  shows its `config.h` default as a hint.
- `POST /settings` runs the validation. On any error it re-renders the form
  with messages beside the fields and saves nothing. On success it saves,
  shows "Saved, restarting", and calls `ESP.restart()` after one second.
- `POST /settings/reset` clears the stored settings and restarts.
- `GET /boot.jpg` returns the stored picture, or the embedded one, for the preview.
- `POST /settings/boot` uploads a picture. `POST /settings/boot/reset`
  deletes `/boot.jpg`.

The page links to `/update` and back, and shows the running commit and uptime.

### Why restart on save

Every v1 setting is read at construction or in `setup()`, as a `const` member
or at a single initialization point. Applying settings live would mean a setter on every widget
and invalidating what is on screen. A restart costs about 14 s, measured
during OTA, and settings change rarely. **Rejected: live apply.**

### Consumers

Each read site in the table swaps its macro for a `Settings` getter. Settings
that today are tested with `#ifdef` (`WEATHER_UNITS_METRIC`,
`DIM_START_HOUR`) become runtime `if`s on a bool. The macro stays in
`config.h` only as the default. `GlobalTime`'s strftime locale strings,
chosen by `#if LOCALE`, are untouched.

**Weather location is URL-encoded** where the request is built
(`WeatherWidget.h:69`). Today the configured town goes into the URL raw with its spaces and
comma. Upstream issue #337 reports that locations containing a space fail. Whether
weather data currently displays for a two-word town has **not been verified** —
check it on the orb before and after this change.

## Boot picture

Upload path: in the browser, the page draws the chosen file onto a 240×240
canvas, center-cropped to a square, and previews it inside a circle. The circle
is what the orb shows. The browser then sends `canvas.toBlob("image/jpeg", q)`. The browser always
produces a **baseline** JPEG, which TJpg_Decoder requires, since it cannot decode
progressive ones. Quality starts at 0.85 and steps down until the file is at
most 64 KB.

The device does not trust the browser. On receipt it checks the SOI marker
`FFD8`, a baseline SOF0 `FFC0` (rejecting progressive `FFC2`), and 240×240 in
the SOF header. It then writes `/boot.tmp` and renames it to `/boot.jpg`, so an interrupted
upload never leaves a half-written picture in place.

Filesystem: `LittleFS.begin(true)` in `setup()`, which formats on first mount.
Nothing calls `begin()` today, so the 128 KB partition has never been
formatted. First boot after this firmware formats it, which takes a few
seconds once.

Draw path (`main.cpp:107`): if `/boot.jpg` exists, draw it from the file. If
the file is missing, or decoding returns an error, draw the embedded logo
instead. A bad file must never leave screen 2 blank.

## Security

Same credentials as `/update`: HTTP basic auth, user `admin`, `OTA_PASSWORD`.
If `OTA_PASSWORD` is unset both pages are open, as `/update` already is. v1
holds no secrets (no keys, no WiFi), and the update page, which can install
arbitrary firmware, is the larger exposure. REQUIREMENTS' security floor ("at
minimum a password") binds when keys move onto the page. The
"Later" item above must make the password mandatory then.

## Error handling

| Failure | Behavior |
|---|---|
| Field fails validation | Form re-shown with the message beside that field; nothing saved |
| NVS write fails | Page says so; no restart; old values still in effect |
| Unknown timezone or weather location | Accepted, because it cannot be checked offline. The existing on-screen error from the API call is what the user sees. Noted beside those fields on the page |
| Boot picture fails the checks | Rejected with the reason (not JPEG / progressive / wrong size / too big) |
| Filesystem full or mount fails | Upload rejected; embedded logo continues |
| Stored `/boot.jpg` will not decode | Embedded logo drawn; the page shows "stored picture unreadable — reset it" |

## Testing

- **Host unit tests** for `SettingsValidation`: a `[env:native]` PlatformIO
  environment with Unity, run via `pio test -e native`. It covers the ticker list
  (1–5, symbols like `BTC/USD` and `SHOP&country=Canada` that the ticker
  comment in `config.h` allows), hour wrap, cycle bounds, empty and over-long text, and
  color hex to RGB565.
- **On the orb**, over OTA. First confirm that a board which never opened the page shows
  exactly what it does today. Then change each v1 setting and check the result on the
  orb, one at a time, reading back from the device and not from the form.
  Then factory reset, and upload a progressive JPEG directly with curl to confirm the device check
  rejects it. Finally upload a real photo through the page, and power-cycle to confirm it persists.
- Flash budget: app is 1,639,797 bytes (83.4% of a slot) before this work.
  Report the new figure. Stop and reassess above 92%.

## Not in this spec

The later-list items; a JSON API for Home Assistant; mDNS naming per orb.

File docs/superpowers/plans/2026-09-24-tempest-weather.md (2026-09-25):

# Tempest Weather Implementation Plan

> **For agentic workers:** REQUIRED SUB-SKILL: Use superpowers:subagent-driven-development (recommended) or superpowers:executing-plans to implement this plan task-by-task. Steps use checkbox (`- [ ]`) syntax for tracking.

**Goal:** Show one five-orb weather page per Tempest station (SLN, LRD) in the rotation, fed from the Tempest cloud API, compiled out unless `TEMPEST_TOKEN` is defined.

**Architecture:** `WeatherWidget` keeps its drawing code and gets a `WeatherSource*`. `VisualCrossingSource` is today's fetch, moved as is. `TempestSource` streams `better_forecast` through an ArduinoJson filter into the same `WeatherDataModel`. `main.cpp` adds one widget per configured station. Pure parsing and validation live in std-only headers, so `pio test -e native` covers them.

**Tech Stack:** PlatformIO espressif32 7.0.1 (Arduino core 2.0.17), ArduinoJson 7, Unity host tests.

**Spec:** `docs/superpowers/specs/2026-09-24-tempest-weather-design.md`

## Global Constraints

- Flash stays **below 92%** of a 1,966,080-byte slot. It was 87.0% before this work. Measure after every task that adds code.
- The SuperMini has **no PSRAM**. Never hold a whole Tempest reply (~96 KB) in RAM: `useHTTP10(true)` + `getStream()` + `DeserializationOption::Filter`.
- The Tempest token lives only in `firmware/config/secrets.h` (git-ignored). It never appears on the settings page, in the repo, or in any output.
- Station IDs, names and coordinates never go in the repo: it is **public**. They live in the git-ignored `config.h` and on the orb.
- With `TEMPEST_TOKEN` undefined, the build and the orb behave **exactly** as on main.
- Every settings-page state keeps a glyph as well as a color (✖/✔/⚠).
- Flash the orb over HTTP: `pio run -e ota` then `curl -F "firmware=@.pio/build/ota/firmware.bin" http://192.168.30.208/update`. Never use espota.
- Before any commit that changes the build, run the exact CI command, a bare `pio run`, plus `pio test -e native`.

## File structure
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

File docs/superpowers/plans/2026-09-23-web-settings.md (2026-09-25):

# Web Settings Page Implementation Plan

> **For agentic workers:** REQUIRED SUB-SKILL: Use superpowers:subagent-driven-development (recommended) or superpowers:executing-plans to implement this plan task-by-task. Steps use checkbox (`- [ ]`) syntax for tracking.

**Goal:** A password-protected `/settings` page on the orb that changes the v1 settings and the boot picture without reflashing.

**Architecture:** `Settings` loads NVS once at boot and falls back to `config.h`. Every read site takes its value from `Settings::get()` instead of a macro. `SettingsPage` registers handlers on the WebServer that `OtaUpdater` already runs. Saving restarts the orb. The boot picture lives in LittleFS as `/boot.jpg`, with the embedded logo as the fallback.

**Tech Stack:** Arduino-ESP32 2.0.17 (PlatformIO espressif32 7.0.1), `Preferences`, `LittleFS`, `WebServer`, TJpg_Decoder `drawFsJpg`, Unity on `platform = native` for host tests.

**Spec:** `docs/superpowers/specs/2026-09-23-web-settings-design.md`
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

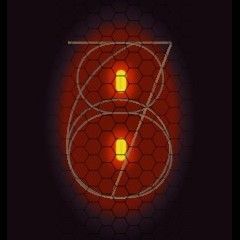
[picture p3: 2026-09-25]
images/ClockWidget/nixie.no-holes/colon_on.jpg

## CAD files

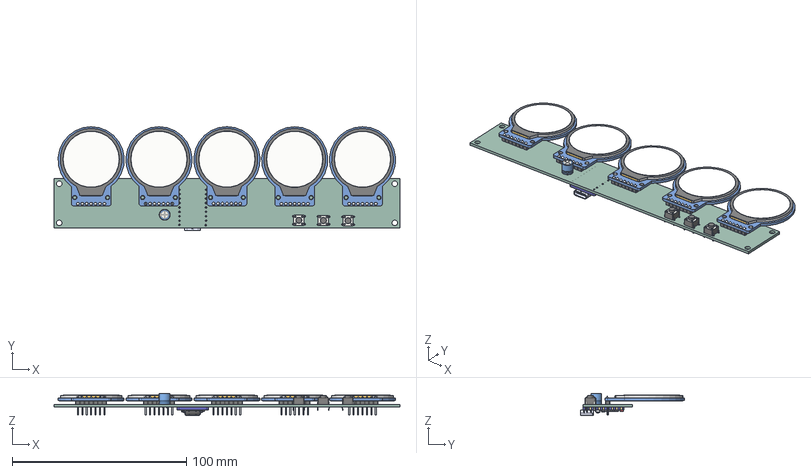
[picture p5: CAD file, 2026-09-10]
hardware/hot-info-orbs/3d-assembly/hot_info_orbs_v1.1_assembly.step
198.8 x 59.6 x 12.9 mm
CP_Radial_D6.3mm_P2.50mm
SW_PUSH_6mm_H5mm x 3
ESP32S3-SuperMini
hot_info_orbs_PCB

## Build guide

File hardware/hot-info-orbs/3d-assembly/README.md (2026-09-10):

# 3D assembly model

`hot_info_orbs_v1.1_assembly.step` — KiCad STEP export of the whole assembly:
PCB, ESP32-S3 SuperMini, five GC9A01 modules, three buttons, C1. For enclosure
design and fit checking.

Exported from Pcbnew **2026-09-09 14:04**, sent by Yang.

**Assembled stack is roughly 40 mm tall** (Z −13.2 to +26.7 mm): the module hangs
below the board, the displays stand above it. That is the dimension an enclosure
has to clear.

## Verify this matches your boards before designing around it

The boards in hand were ordered **2026-08-29** from tag `v1.1-run1`. This model
was exported **eleven days later**. If the board moved in between, the model
describes hardware nobody has. Confirm before cutting an enclosure to it.

## Why it arrived as a .bin

It was saved out of KiCad with no filename — the STEP header records the name as
literally `.step`, no stem. Messages had nothing to work with, so it substituted
a send-timestamp and a generic `.bin` extension. Renamed here; contents
unaltered (md5 `20c54433dd50a71e634d8743aad6edbf`).

Displays and module are shown as if soldered flat. Sockets will stand both
further off the board than this model suggests — Yang's note, 2026-08-29.

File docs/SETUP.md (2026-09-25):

# Setting Up Info Orbs From Scratch

Written for someone who has never used PlatformIO. If you have, skip to
[step 3](#3-create-your-two-config-files) — the only thing that has changed from
upstream is that there are now **two** files to copy, not one.

Budget about 45 minutes the first time. Most of that is downloads.

---

## What you need before you start

- The assembled orbs hardware (ESP32-S3 SuperMini + five round displays + three buttons)
- A **USB data cable**. Many cheap USB cables carry power only. If the board
  never shows up as a port, suspect the cable before anything else.
- A 2.4 GHz WiFi network. The ESP32 cannot see 5 GHz networks at all.
- About 1 GB of free disk for the toolchain.

---

## 1. Install VS Code and PlatformIO

1. Install [Visual Studio Code](https://code.visualstudio.com/).
2. Open VS Code, click the **Extensions** icon in the left bar (four squares).
3. Search for `PlatformIO IDE` and install it.
4. **Restart VS Code, then wait.** On first launch PlatformIO downloads and
   builds its own Python environment. This takes several minutes and shows a
   progress notice in the bottom-right. Do not start a build until it finishes.

> PlatformIO redoes this bootstrap after some VS Code updates. If builds
> suddenly break on a machine that used to work, that is usually why — see
> [Troubleshooting](#troubleshooting).

## 2. Get the code

If you use git:

```bash
git clone https://github.com/scottdube/hot-info-orbs.git
cd hot-info-orbs
```

If you don't: click the green **Code** button on the repository page, choose
**Download ZIP**, and unzip it somewhere you can find again. Avoid a path with
spaces or accents in it — some toolchain steps still trip on those.

Then in VS Code: **File → Open Folder**, and pick the `hot-info-orbs` folder
(from a ZIP it may be `hot-info-orbs-main`). Opening
the folder (not a single file) is what makes PlatformIO recognize the project.

## 3. Create your two config files

In `firmware/config/` you will find two `.template` files. Make a copy of each,
in the same folder, with the `.template` dropped from the name:

| Copy this | To this | What it holds |
|---|---|---|
| `config.h.template`  | `config.h`  | your preferences — timezone, units, tickers  |
| `secrets.h.template` | `secrets.h` | your API keys, and WiFi/MQTT if you use them |

```bash
cd firmware/config
cp config.h.template config.h
cp secrets.h.template secrets.h
```

**Both are required.** The build refuses to start without them and tells you
which one is missing. That is deliberate — better than a blank orb on the bench.

**Why two files:** `config.h` and `secrets.h` are both ignored by git, so nothing
personal ever gets committed. The `.template` files are the ones tracked in git,
which is why they must never contain real values. If you ever edit a `.template`
file, put placeholders in it, not your own keys.

## 4. Get your two API keys

Both are free, both take about a minute, and **you need your own**. A key shared
across several orbs burns one free-tier quota and gets rate-limited, and whoever
owns it can revoke it without warning.

| Key | Register at | What it does |
|---|---|---|
| `WEATHER_API_KEY`  | [visualcrossing.com/sign-up](https://www.visualcrossing.com/sign-up) | Current conditions and forecast for the weather orb. Free tier is ~1000 records/day, far more than one orb uses. |
| `TIMEZONE_API_KEY` | [timezonedb.com/register](https://timezonedb.com/register) | Your UTC offset and the next daylight-saving changeover. |

A note on the second one, because the name misleads: TimeZoneDB is **not** where
the orb gets the time. The time comes from NTP (`pool.ntp.org`). TimeZoneDB
supplies only the offset and the DST transition date — which is how the clock
fixes itself every March and November without anyone reflashing it.

Paste each key between the quotes in `secrets.h`:

```c
#define WEATHER_API_KEY "your-key-here"
#define TIMEZONE_API_KEY "your-key-here"
```

Leaving one empty fails the build with a message naming the key. It will not let
you flash a half-configured orb.

## 5. Set your preferences in `config.h`

Open `firmware/config/config.h`. Everything above the
`END OF USER CONFIGURATION` banner is meant to be edited; below it is hardware
wiring you should leave alone unless you built a variant board.

The four settings most people want to change:

```c
#define TIMEZONE_API_LOCATION "America/New_York"  // from https://timezonedb.com/time-zones
#define WEATHER_LOCATION "The Villages, FL"       // city, state
//#define WEATHER_UNITS_METRIC                    // uncomment for celsius
#define STOCK_TICKER_LIST "SPY,QQQ,AAPL,MSFT,BTC/USD"  // exactly 5
```

Worth knowing about the ticker list: it takes five symbols. Crypto and forex
need a currency pair (`BTC/USD`). For a symbol that trades on more than one
exchange, append the country (`APC&country=Germany`).

Other things you can turn on here: dim hours and screens-off hours (separate schedules), a Nixie-tube clock face,
24-hour time, widget auto-cycling. Each is commented in the file.

## 6. Build and upload

1. Plug the orbs into USB.
2. Click the **PlatformIO icon** (the alien head) in the left bar.
3. Under **Project Tasks → esp32-s3-devkitc-1 → General**, click **Upload**.

The first build downloads the ESP32 platform and compiler — several hundred MB,
several minutes, once. Later builds take about 15 seconds.

When it starts, one orb shows **Welcome** and how full the firmware slot is,
e.g. `Flash 87%`. The project keeps that under 92% so updates always fit.

If upload cannot find the board, put it in download mode by hand: unplug the
USB cable, hold the **BOOT** button on the SuperMini, plug the cable back in,
release, then click Upload. (The BOOT and RST labels can be hard to read. If
no new port appears, try the other button: RST only restarts the board.)

## 7. Connect it to WiFi

The orbs create their own WiFi network on first boot. On a phone or laptop, join
the network the orbs advertise, and a configuration page opens automatically.
Pick your home network from the list and enter its password.

This is stored on the device, not in your files. You do not reflash to change
WiFi later — hold the buttons per the on-screen prompts to reopen the portal.

## 8. Later updates: no cable needed

Once the orbs are on your WiFi, new firmware goes over the network. The **first**
flash has to be over USB (step 6), because it also writes the partition layout
that makes network updates possible.

- **From a browser:** build as usual, then open `http://info-orbs.local/update`,
  choose `.pio/build/esp32-s3-devkitc-1/firmware.bin` and press Upload. If
  `.local` names do not resolve on your computer, use the IP address shown on
  the orbs when they connect.
- **From PlatformIO:** `pio run -e ota -t upload`. This needs the orb to connect
  *back* to your computer, which fails when the two are on different subnets,
  and a failed attempt restarts the orb. If it says `No response from device`,
  wait until the update page loads again and use the browser.

**The password is optional.** Set `OTA_PASSWORD` in `secrets.h` and the browser
asks for user `admin` and that password on both the update and settings pages.
Without one, anyone on your network can flash the orbs or change their
settings, and both pages show a ⚠ warning saying so.

A failed or interrupted update keeps the old firmware. A new firmware that
installs but cannot get back on WiFi is rolled back when it next restarts.

## 9. Change settings from a browser

Open `http://<orb's IP>/settings` (or `http://info-orbs.local/settings`) on a
phone or computer on the same network. It uses the same optional `admin` /
`OTA_PASSWORD` login as the update page. The page never shows your API keys.

- **Save and restart** stores the changes and restarts the orbs, about 15 s.
  The page reloads by itself. A value that fails its check is shown beside
  that field, and nothing is saved.
- **Reset to built-in values** forgets everything saved from the page and goes
  back to what `config.h` says.
- **Start-up picture:** pick any photo. The page crops it to a centered square
  and shows the circle the orb will display. **Upload and restart** puts it on the
  middle orb at start-up. **Use the built-in logo** takes it off again.

Settings survive restarts and firmware updates. A USB flash with **Erase
Flash** first clears them.
Timezone and weather location cannot be checked until the orb uses them. If
you mistype one, the clock or weather orb shows the error.

## 10. Optional: weather from your own Tempest stations

If you own a WeatherFlow Tempest station, the orbs can show its weather
instead of Visual Crossing's, with one weather page per station (up to two).

1. Get a token: tempestwx.com > Settings > Data Authorizations > Create Token.
   Add it to `secrets.h`: `#define TEMPEST_TOKEN "..."`.
2. Find each station's ID: the number in the station's tempestwx.com address.
   Put the IDs, and a short label for each (16 characters at most, shown in place
   of the town name), in `config.h` (see the commented `TEMPEST_STATION_1` lines
   in the template), or enter them on the settings page later.
3. Build and upload. The settings page gets a **Tempest stations** section
   where each station shows ✔ or ✖ for its last fetch, how long ago it was, and
   the error if it failed.

The token never appears on the settings page. Leave `TEMPEST_TOKEN` out and
the Tempest code is not compiled in at all.

---

## Troubleshooting

| Symptom | Cause and fix |
|---|---|
| `Copy firmware/config/secrets.h.template…` | You missed step 3. Copy both templates. |
| `WEATHER_API_KEY is empty…` | `secrets.h` exists but a key is still `""`. See step 4. |
| `ModuleNotFoundError: No module named 'intelhex'` | PlatformIO bootstrapped a fresh Python environment (often after a VS Code update) and missed a dependency of its flashing tool. Fix: `~/.platformio/penv/bin/python -m pip install intelhex` |
| No serial port listed | Suspect the USB cable first — many are charge-only. The SuperMini uses the ESP32-S3's own USB, so no CP2102/CH340 driver is needed. If the orbs still answer on WiFi, they are fine: enter download mode (step 6) and reflash. |
| Upload starts then fails | Enter download mode by hand: hold **BOOT** while plugging the cable in, then Upload (step 6). |
| Clock right, weather orb blank | The weather key is wrong or its quota is spent. A bad key fails silently at runtime — it cannot be caught at build time. |
| Never finds your WiFi | The network is 5 GHz. The ESP32 only sees 2.4 GHz. |
| Builds broke on a machine that worked before | A VS Code update replaced PlatformIO's Python environment. Reopen the project folder in VS Code and let the bootstrap finish, then see the `intelhex` row above. |
| Time is an hour off after a DST change | The timezone key is wrong or out of quota — that is the service that supplies the changeover. |

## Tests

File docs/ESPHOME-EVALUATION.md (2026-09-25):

# Could this run on ESPHome instead?

Evaluated 2026-08-27. **Answer: not on this hardware — ESPHome buffers each
display in RAM and five will not fit.** The idea is sound and the reasons it
fails are specific, so they are recorded rather than the conclusion alone.

## Why it was worth asking

ESPHome would provide, as built-in components rather than as work:

| Requirement | ESPHome |
|---|---|
| R2 — OTA updates | `ota:` component, native |
| R1 — remote configuration | `web_server:` component |
| Secrets handling | `secrets.yaml`, the exact pattern hand-built in `secrets.h` |
| Config format | YAML instead of C++ |

And one thing not on the requirements list that may matter more than both:
**Home Assistant integration would remove the API keys entirely.** Weather could
come from an existing HA weather entity rather than Visual Crossing; there would
be no key to register, no free-tier quota, and no key to leak. For builders new
to embedded work, YAML with no compile step is a genuinely lower wall than a C++
toolchain.

## Why it does not work

ESPHome supports GC9A01A through the `ili9xxx` display component (added March
2024). That component **allocates a full framebuffer per display**. There is an
open feature request for partial buffering on low-RAM devices
([esphome/feature-requests#3131](https://github.com/esphome/feature-requests/issues/3131)),
which is itself confirmation that full-buffer is the current behavior.

The numbers, using the DRAM budget measured from our own build rather than a
datasheet figure:

```
DRAM budget (from `pio run`)   327,680 B
current firmware uses           53,084 B   (16.2%)
free                           274,596 B
```

| Color depth | Per display | Five displays | |
|---|---:|---:|---|
| 16-bit | 115,200 B | 576,000 B | **2.1× the free DRAM** |
| 8-bit | 57,600 B | 288,000 B | **still over** |

Even at 8-bit color, five buffers exceed the entire free DRAM before ESPHome's
own runtime, the WiFi stack, or anything else is accounted for.

ESPHome's own documentation says as much in passing: *"16 bit colors requires
twice the amount of RAM as 8 bit, and may not be usable unless PSRAM is
available."*

## Why the current firmware does fit

TFT_eSPI does not keep a framebuffer. It streams pixels straight out over SPI
as it draws. That is precisely how five 240×240 panels fit on a chip with 320 KB
of DRAM, and it is the architectural difference that decides this question.

## What would change the answer

**PSRAM.** An ESP32-WROVER (4–8 MB PSRAM) or an S3 variant carrying PSRAM has
room for five buffers. Note the irony: choosing ESPHome would reopen the module
question that was just closed on complexity and cost grounds, and push toward a
*more* expensive board. That is the opposite of the direction this project is
going.

Partial-buffer support landing in ESPHome would also change it, but that is an
open feature request, not a plan.

## The part worth keeping

The most attractive thing about the ESPHome route — sourcing data from Home
Assistant instead of third-party APIs — **does not require ESPHome.**

Upstream already ships an MQTT widget, and there is a Home Assistant blueprint
for it at [dreed47/info-orbs-mqtt-ha](https://github.com/dreed47/info-orbs-mqtt-ha).
An orb can subscribe to HA-published topics and display whatever HA already
knows: weather, sensors, energy, presence. No API keys, no quotas, no rewrite,
and it works on the dev-kit hardware already chosen.

**Recommendation: keep the Arduino firmware, and use the existing MQTT widget
for anything Home Assistant can supply.** That captures the real benefit of the
ESPHome idea at a fraction of the cost, and leaves the graphics work — the nixie
clock, the weather icons, the TrueType fonts — untouched rather than
reimplemented against a more limited drawing API.

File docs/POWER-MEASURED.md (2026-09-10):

# Power: measured, 2026-09-10

Every power figure in this project was an estimate until this. Measured on the
first assembled board — five GC9A01 displays, ESP32-S3 SuperMini, running the
ported firmware on WiFi.

**Instrument:** Nordic PPK II, source meter mode, 5.000 V, 10 kSa/s, 10 s window.

| | |
|---|---|
| Average | **341.79 mA** → **1.71 W** |
| Max (10 s window) | 399.87 mA → 2.00 W |
| **Boot inrush** | **1.15 A peak**, milliseconds, measured |

## What it settles

The estimate this project ran on was ~380 mA (five displays at 40–80 mA plus an
ESP32 averaging ~80 mA). Measured 342 mA, so **the estimate was 11% high** —
close enough that everything built on it stands.

**The 5 V decision is vindicated with numbers.** Upstream powers all five
displays from the module's own 3.3 V regulator. Had this load gone that way:

```
(5.0 − 3.3) × 342 mA = 581 mW in a SOT-23-5
  → junction 112–170 °C depending on copper
  → LDO thermal shutdown is 150–165 °C
```

At or past shutdown. That is what the field reports were describing — one
builder measured 82 °C **with the radio off, running only a graphics demo**.

As built, each display regulates its own 5 V and the module's LDO carries only
the ESP32: roughly 80 mA average, ~136 mW, ~52 °C. The part that was cooking is
no longer in the path.

## Boot inrush: 1.15 A, measured

**Corrected 2026-09-10.** An earlier draft recorded this as ">1 A, clipped",
assuming the PPK II source meter limited at 1 A. It does not — it read the peak
directly at **1.15 A**.

Second capture, 3 s window at 10 kSa/s covering power-on:

| | |
|---|---|
| Peak | **1.15 A**, a single narrow spike at power-on |
| Settles to | ~240 mA |
| Then steps | ~270 mA → ~300 mA as displays come up |
| Then | ~340 mA with WiFi bursts to ~450 mA |
| Window average over the 3 s | 270 mA, 0.81 C |

The staged ramp is five display regulators starting in sequence, then the radio
joining the network.

**What it means for supply choice: 1.15 A is 3.4x the running current.** A
supply sized for the 342 mA average will sag at power-on. The failure that
produces is an orb which starts on one charger and not another, with nothing
wrong with the orb — and it will be blamed on the firmware.

## For pricing and supply choice

1.71 W typical, but **size the supply for the 1.15 A inrush, not the 342 mA
average**. 2 A is a sensible floor and costs nothing; 1 A is not enough despite
being nearly 3x the running current.

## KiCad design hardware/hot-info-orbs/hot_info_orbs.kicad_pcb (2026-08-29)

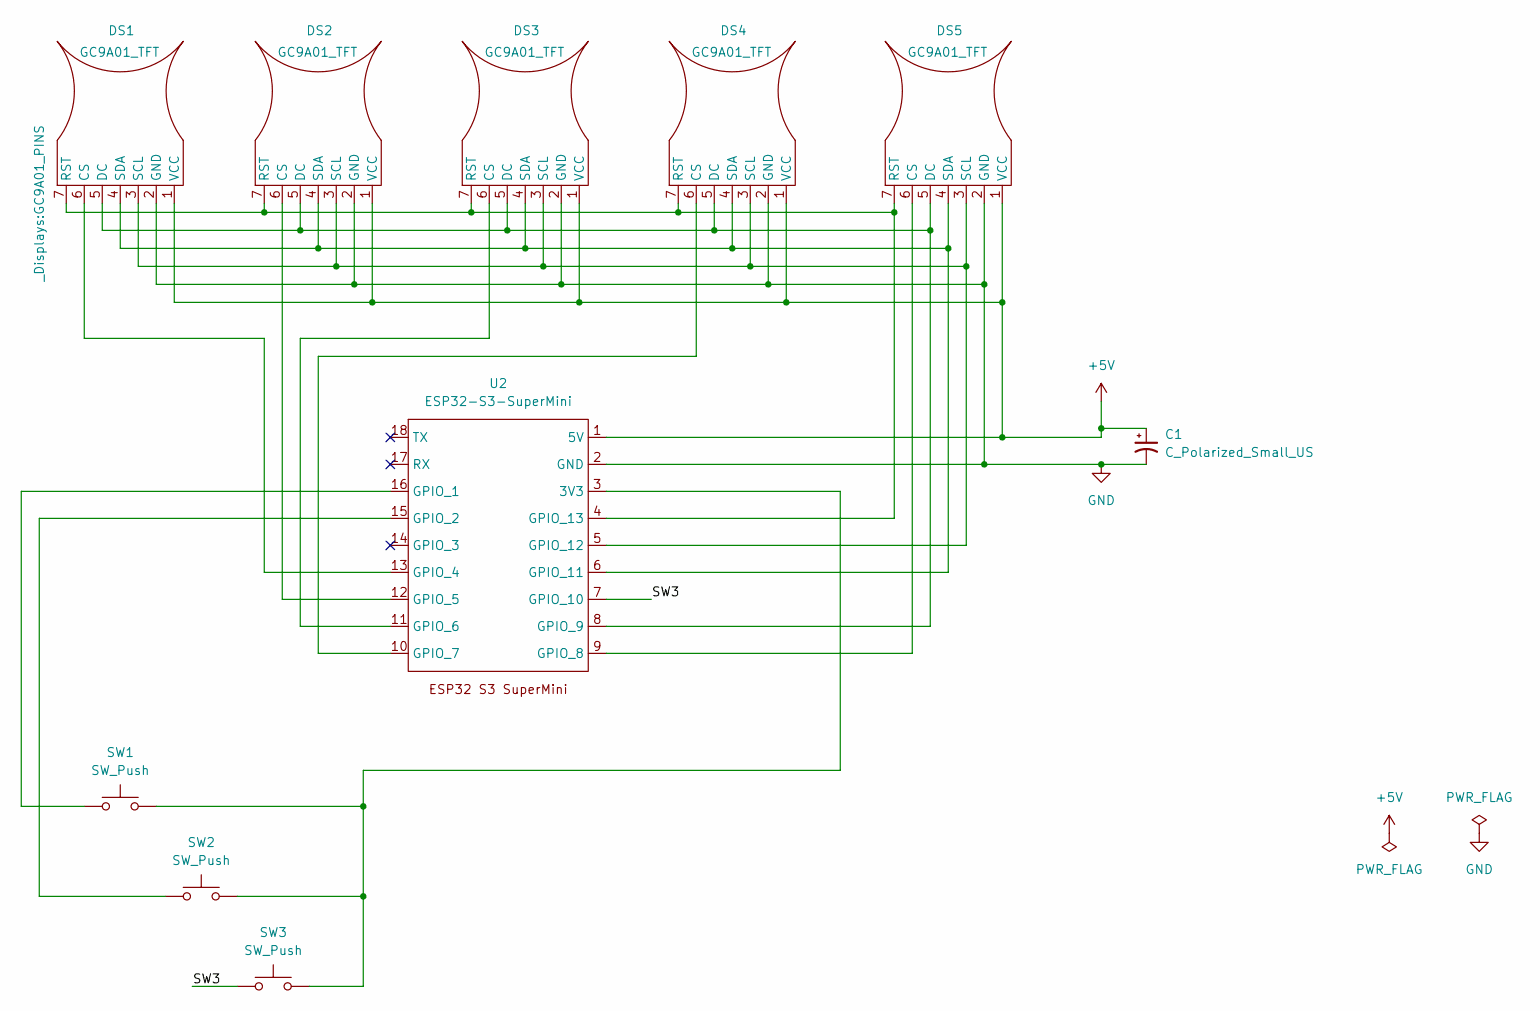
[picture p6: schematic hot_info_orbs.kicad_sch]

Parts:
C1: C_Polarized_Small_US; CP_Radial_D6.3mm_P2.50mm
DS1, DS2, DS3, DS4, DS5: GC9A01_TFT; GC9A01_PINS
SW1, SW2, SW3: SW_Push; SW_PUSH_6mm_H5mm
U2: ESP32-S3-SuperMini; ESP32S3-SuperMini

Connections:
+5V: C1.1, DS1.1 (VCC), DS2.1 (VCC), DS3.1 (VCC), DS4.1 (VCC), DS5.1 (VCC), U2.1 (5V)
/SW3: SW3.1, U2.7 (GPIO_10)
GND: C1.2, DS1.2 (GND), DS2.2 (GND), DS3.2 (GND), DS4.2 (GND), DS5.2 (GND), U2.2 (GND)
unnamed: DS1.6 (CS), U2.13 (GPIO_4)
unnamed: DS1.5 (DC), DS2.5 (DC), DS3.5 (DC), DS4.5 (DC), DS5.5 (DC), U2.8 (GPIO_9)
unnamed: DS1.7 (RST), DS2.7 (RST), DS3.7 (RST), DS4.7 (RST), DS5.7 (RST), U2.4 (GPIO_13)
unnamed: DS1.3 (SCL), DS2.3 (SCL), DS3.3 (SCL), DS4.3 (SCL), DS5.3 (SCL), U2.5 (GPIO_12)
unnamed: DS1.4 (SDA), DS2.4 (SDA), DS3.4 (SDA), DS4.4 (SDA), DS5.4 (SDA), U2.6 (GPIO_11)
unnamed: DS2.6 (CS), U2.12 (GPIO_5)
unnamed: DS3.6 (CS), U2.11 (GPIO_6)
unnamed: DS4.6 (CS), U2.10 (GPIO_7)
unnamed: DS5.6 (CS), U2.9 (GPIO_8)
unnamed: SW1.2, SW2.2, SW3.2, U2.3 (3V3)
unnamed: SW1.1, U2.16 (GPIO_1)
unnamed: SW2.1, U2.15 (GPIO_2)

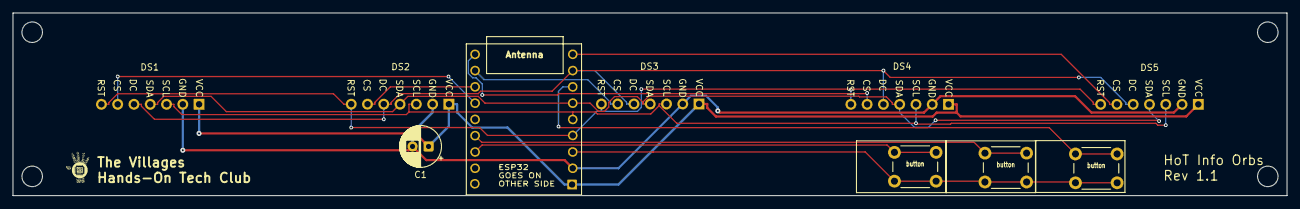
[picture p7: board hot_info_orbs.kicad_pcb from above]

Board: 2 copper layers, 198.8 x 28.5 mm, 10 parts (1 on the bottom side), 15 nets.

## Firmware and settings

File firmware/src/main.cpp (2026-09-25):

#include "Button.h"
#include "GlobalTime.h"
#include "OtaUpdater.h"
#include "ScreenManager.h"
#include "Settings.h"
#include "SettingsPage.h"
#include "Utils.h"
#include "WidgetSet.h"
#include "clockwidget/ClockWidget.h"
#include "config_helper.h"
#include "icons.h"
#include "weatherwidget/TempestSource.h"
#include "weatherwidget/VisualCrossingSource.h"
#include "weatherwidget/WeatherWidget.h"
#include "webdatawidget/WebDataWidget.h"
#include "wifiwidget/WifiWidget.h"
#include <Arduino.h>
#include <LittleFS.h>

#ifdef STOCK_TICKER_LIST
    #include "stockwidget/StockWidget.h"
#endif
#ifdef PARQET_PORTFOLIO_ID
    #include "parqetwidget/ParqetWidget.h"
#endif
#ifdef MQTT_WIDGET_HOST
    #include "mqttwidget/MQTTWidget.h"
#endif

TFT_eSPI tft = TFT_eSPI();

unsigned long m_widgetCycleDelay = 0; // ms between automatic widget changes, 0 = off; set from Settings in setup()
unsigned long m_widgetCycleDelayPrev = 0;

Button buttonLeft(BUTTON_LEFT);
Button buttonOK(BUTTON_OK);
Button buttonRight(BUTTON_RIGHT);

GlobalTime *globalTime; // Initialize the global time

String connectingString{""};

WifiWidget *wifiWidget{nullptr};
OtaUpdater *otaUpdater{nullptr};
SettingsPage *settingsPage{nullptr};

int connectionTimer{0};
const int connectionTimeout{10000};
bool isConnected{true};

ScreenManager *sm;
WidgetSet *widgetSet;

// This function should probably be moved somewhere else
bool tft_output(int16_t x, int16_t y, uint16_t w, uint16_t h, uint16_t *bitmap) {
    if (y >= tft.height())
        return 0;
    // Dim bitmap
    for (int i = 0; i < w * h; i++) {
        bitmap[i] = Utils::rgb565dim(bitmap[i], sm->getBrightness(), true);
    }
    tft.pushImage(x, y, w, h, bitmap);
    return 1;
}

/**
 * The ISR handlers must be static
 */
void isrButtonChangeLeft() { buttonLeft.isrButtonChange(); }
void isrButtonChangeMiddle() { buttonOK.isrButtonChange(); }
void isrButtonChangeRight() { buttonRight.isrButtonChange(); }

void setupButtons() {
    buttonLeft.begin();
    buttonOK.begin();
    buttonRight.begin();

    attachInterrupt(digitalPinToInterrupt(BUTTON_LEFT), isrButtonChangeLeft, CHANGE);
    attachInterrupt(digitalPinToInterrupt(BUTTON_OK), isrButtonChangeMiddle, CHANGE);
    attachInterrupt(digitalPinToInterrupt(BUTTON_RIGHT), isrButtonChangeRight, CHANGE);
}

void setup() {
    Serial.begin(115200);
    Serial.println();
    Serial.println("Starting up...");

    // Before anything is constructed: ScreenManager, GlobalTime and every
    // widget read their settings once, at construction
    Settings::load();
    m_widgetCycleDelay = Settings::get().cycle * 1000UL;

    // Holds the uploaded boot picture. true = format if it will not mount: a
    // new board's partition has never been formatted (a few seconds, once)
    bool fsMounted = LittleFS.begin(true);
    Serial.printf("LittleFS %s\n", fsMounted ? "mounted" : "FAILED - built-in logo only");

    TJpgDec.setSwapBytes(true); // JPEG rendering setup
    TJpgDec.setCallback(tft_output);
    setupButtons();

    sm = new ScreenManager(tft);
    sm->fillAllScreens(TFT_BLACK);
    sm->setFontColor(TFT_WHITE);

    sm->selectScreen(0);
    sm->drawCenterString("Welcome", ScreenCenterX, ScreenCenterY, 29);
    // Running image against one OTA slot: the figure the 92% stop line is
    // measured against, read from the image so it always matches what runs
    uint32_t used = ESP.getSketchSize(), slot = ESP.getFreeSketchSpace();
    if (slot > 0) {
        char line[32];
        snprintf(line, sizeof(line), "Flash %u%%", (unsigned)((used * 100ULL + slot / 2) / slot));
        sm->drawCenterString(line, ScreenCenterX, ScreenCenterY + 45, 22);
        unsigned u = used / 1024, t = slot / 1024; // KB; under 10,000 on any 4-16 MB part
        snprintf(line, sizeof(line), "%u,%03u / %u,%03u KB", u / 1000, u % 1000, t / 1000, t % 1000);
        sm->drawCenterString(line, ScreenCenterX, ScreenCenterY + 75, 14);
    }

    sm->selectScreen(1);
    sm->drawCenterString("HOT Info Orbs", ScreenCenterX, ScreenCenterY - 50, 22);
    sm->drawCenterString("by", ScreenCenterX, ScreenCenterY - 5, 22);
    sm->drawCenterString("HOT-Team", ScreenCenterX, ScreenCenterY + 30, 22);
    sm->setFontColor(TFT_RED);
    sm->drawCenterString("version: " FIRMWARE_VERSION, ScreenCenterX, ScreenCenterY + 65, 14);

    sm->selectScreen(2);

    TJpgDec.setJpgScale(1);
    // The uploaded picture if there is one and it decodes; the built-in logo
    // otherwise, drawn over whatever part of a bad file got drawn
    bool pictureUnreadable = false;
    if (fsMounted && LittleFS.exists("/boot.jpg")) {
        pictureUnreadable = TJpgDec.drawFsJpg(0, 0, "/boot.jpg", LittleFS) != JDR_OK;
    }
    if (!fsMounted || !LittleFS.exists("/boot.jpg") || pictureUnreadable) {
        TJpgDec.drawJpg(0, 0, logo_start, logo_end - logo_start);
    }
    SettingsPage::setBootStatus(fsMounted, pictureUnreadable);

    widgetSet = new WidgetSet(sm);

#ifdef GC9A01_DRIVER
    Serial.println("GC9A01 Driver");
#endif
#if HARDWARE == WOKWI
    Serial.println("Wokwi Build");
#endif

    pinMode(BUSY_PIN, OUTPUT);
    Serial.println("Connecting to WiFi");

    wifiWidget = new WifiWidget(*sm);
    otaUpdater = new OtaUpdater(*sm);
    settingsPage = new SettingsPage(*otaUpdater);
    wifiWidget->setup();

    globalTime = GlobalTime::getInstance();

    widgetSet->add(new ClockWidget(*sm));
#ifdef PARQET_PORTFOLIO_ID
    widgetSet->add(new ParqetWidget(*sm));
#endif
#ifdef STOCK_TICKER_LIST
    if (!Settings::get().tickers.empty()) {
        widgetSet->add(new StockWidget(*sm));
    }
#endif
    bool tempestPages = false;
#ifdef TEMPEST_TOKEN
    // One weather page per Tempest station; Visual Crossing only when none is set
    const SettingsValues &wx = Settings::get();
    if (wx.tstn1) {
        widgetSet->add(new WeatherWidget(*sm, new TempestSource(0, wx.tstn1, wx.tlbl1)));
        tempestPages = true;
    }
    if (wx.tstn2) {
        widgetSet->add(new WeatherWidget(*sm, new TempestSource(1, wx.tstn2, wx.tlbl2)));
        tempestPages = true;
    }
#endif
    if (!tempestPages) {
        widgetSet->add(new WeatherWidget(*sm, new VisualCrossingSource()));
    }
#ifdef WEB_DATA_WIDGET_URL
    widgetSet->add(new WebDataWidget(*sm, WEB_DATA_WIDGET_URL));
#endif
#ifdef WEB_DATA_STOCK_WIDGET_URL
    widgetSet->add(new WebDataWidget(*sm, WEB_DATA_STOCK_WIDGET_URL));
#endif
#ifdef MQTT_WIDGET_HOST
    widgetSet->add(new MQTTWidget(*sm, MQTT_WIDGET_HOST, MQTT_WIDGET_PORT));
#endif
    settingsPage->setWidgets(widgetSet);

    m_widgetCycleDelayPrev = millis();
}

void checkCycleWidgets() {
    if (m_widgetCycleDelay > 0 && (m_widgetCycleDelayPrev == 0 || (millis() - m_widgetCycleDelayPrev) >= m_widgetCycleDelay)) {
        widgetSet->next();
        m_widgetCycleDelayPrev = millis();
    }
}

void checkButtons() {
    // While the panels are off, a press only wakes them; it does not also act
    if (widgetSet->panelsAsleep()) {
        bool pressed = buttonLeft.getState() != BTN_NOTHING;
        pressed = buttonOK.getState() != BTN_NOTHING || pressed;
        pressed = buttonRight.getState() != BTN_NOTHING || pressed;
        if (pressed) {
            Serial.println("Button pressed -> wake panels for a minute");
            m_widgetCycleDelayPrev = millis();
            widgetSet->wakeForAMinute();
        }
        return;
    }
    // Reset cycle timer whenever a button is pressed
    if (buttonLeft.pressedShort()) {
        // Left short press cycles widgets backward
        Serial.println("Left button short pressed -> switch to prev Widget");
        m_widgetCycleDelayPrev = millis();
        widgetSet->prev();
    } else if (buttonRight.pressedShort()) {
        // Right short press cycles widgets forward
        Serial.println("Right button short pressed -> switch to next Widget");
        m_widgetCycleDelayPrev = millis();
        widgetSet->next();
    } else {
        ButtonState leftState = buttonLeft.getState();
        ButtonState middleState = buttonOK.getState();
        ButtonState rightState = buttonRight.getState();

        // Everying else that is not BTN_NOTHING will be forwarded to the current widget
        if (leftState != BTN_NOTHING) {
            Serial.printf("Left button pressed, state=%d\n", leftState);
            m_widgetCycleDelayPrev = millis();
            widgetSet->buttonPressed(BUTTON_LEFT, leftState);
        } else if (middleState != BTN_NOTHING) {
            Serial.printf("Middle button pressed, state=%d\n", middleState);
            m_widgetCycleDelayPrev = millis();
            widgetSet->buttonPressed(BUTTON_OK, middleState);
        } else if (rightState != BTN_NOTHING) {
            Serial.printf("Right button pressed, state=%d\n", rightState);
            m_widgetCycleDelayPrev = millis();
            widgetSet->buttonPressed(BUTTON_RIGHT, rightState);
        }
    }
}

void loop() {
    if (wifiWidget->isConnected() == false) {
        wifiWidget->update();
        wifiWidget->draw();
        widgetSet->setClearScreensOnDrawCurrent(); // Clear screen after wifiWidget
        delay(100);
    } else {
        if (!widgetSet->initialUpdateDone()) {
            widgetSet->initializeAllWidgetsData();
        }
        otaUpdater->begin(); // no-op after the first call
        settingsPage->begin(); // same server, so after OTA's
        otaUpdater->handle();
        if (otaUpdater->isUpdating()) {
            return; // leave the CPU and screen 2 to the upload
        }
        wifiWidget->roamIfWeak();
        globalTime->updateTime();

        checkButtons();

        widgetSet->updateCurrent();
        widgetSet->updateBrightnessByTime(globalTime->getHour24());
        if (!widgetSet->panelsAsleep()) {
            widgetSet->drawCurrent();
            checkCycleWidgets(); // a switch redraws all five screens
        }
    }
}

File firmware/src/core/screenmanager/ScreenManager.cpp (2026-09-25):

#include "ScreenManager.h"
#include "Settings.h"
#include "Utils.h"
#include <Arduino.h>

ScreenManager::ScreenManager(TFT_eSPI &tft) : m_tft(tft) {

    for (int i = 0; i < NUM_SCREENS; i++) {
        pinMode(m_screen_cs[i], OUTPUT);
        digitalWrite(m_screen_cs[i], LOW);
    }

    m_tft.init();
    m_tft.setRotation(Settings::get().invert ? 2 : 0);
    m_tft.fillScreen(TFT_WHITE);
    m_tft.setTextDatum(MC_DATUM);
    reset();

    // I'm not sure which cache size is actually good.
    // Needs testing.
    m_render.setCacheSize(128, 128, 8192);
    setFont(DEFAULT_FONT);
    m_render.setDrawer(m_tft);

    Serial.println("ScreenManager initialized");
    Serial.println("TFT_MOSI:" + String(TFT_MOSI));
    Serial.println("TFT_MISO:" + String(TFT_MISO));
    Serial.println("TFT_SCLK:" + String(TFT_SCLK));
    Serial.println("TFT_CS:" + String(TFT_CS));
    Serial.println("TFT_DC:" + String(TFT_DC));
    Serial.println("TFT_RST:" + String(TFT_RST));
    Serial.println("SCREEN_1_CS:" + String(SCREEN_1_CS));
    Serial.println("SCREEN_2_CS:" + String(SCREEN_2_CS));
    Serial.println("SCREEN_3_CS:" + String(SCREEN_3_CS));
    Serial.println("SCREEN_4_CS:" + String(SCREEN_4_CS));
    Serial.println("SCREEN_5_CS:" + String(SCREEN_5_CS));
}

void ScreenManager::setFont(TTF_Font font) {
    if (font == m_curFont) {
        // nothing to do
        return;
    }
    m_render.unloadFont();
    // Font is now unloaded
    m_curFont = TTF_Font::NONE;
    if (font == TTF_Font::NONE) {
        // just unload
        return;
    }
    // 0 is success
    FT_Error error = 1;
    switch (font) {
    case ROBOTO_REGULAR:
        error = m_render.loadFont(robotoRegular_start, robotoRegular_end - robotoRegular_start);
        break;

#ifdef USE_FINAL_FRONTIER
    case FINAL_FRONTIER:
        error = m_render.loadFont(finalFrontier_start, finalFrontier_end - finalFrontier_start);
        break;
#endif

    case DSEG7:
        error = m_render.loadFont(dseg7_start, dseg7_end - dseg7_start);
        break;

    case DSEG14:
        error = m_render.loadFont(dseg14_start, dseg14_end - dseg14_start);
        break;
    }
    if (error == 0) {
        m_curFont = font;
    } else {
        Serial.printf("Unable to load TTF font %d\n", font);
    }
}

TFT_eSPI &ScreenManager::getDisplay() {
    return m_tft;
}

OpenFontRender &ScreenManager::getRender() {
    return m_render;
}

// Selects a single screen
void ScreenManager::selectScreen(int screen) {
    for (int i = 0; i < NUM_SCREENS; i++) {
        int currentDisplay = Settings::get().invert ? NUM_SCREENS - i - 1 : i;
        digitalWrite(m_screen_cs[currentDisplay], i == screen ? LOW : HIGH);
    }
}

// Fills all screens with a color
void ScreenManager::fillAllScreens(uint32_t color) {
    selectAllScreens();
    fillScreen(color);
    reset();
}

// Clears all screens by resetting them to black
void ScreenManager::clearAllScreens() {
    fillAllScreens(TFT_BLACK);
}

// Clears one screens by resetting it to black
void ScreenManager::clearScreen(int screen) {
    if (screen >= 0) {
        selectScreen(screen);
    }
    fillScreen(TFT_BLACK);
}

void ScreenManager::fillScreen(uint32_t color) {
    m_tft.fillScreen(dim(color));
    // Set background for aliasing as well
    m_render.setBackgroundColor(dim(color));
}

bool ScreenManager::setBrightness(uint8_t brightness) {
    if (m_brightness != brightness) {
        Serial.printf("Brightness set to %d\n", brightness);
        m_brightness = brightness;
        return true;
    } else {
        return false;
    }
}

// Display off + sleep on every panel at once (GC9A01 commands 0x28/0x10), and
// back. Frame memory is redrawn by the caller after waking.
void ScreenManager::setPanelsAsleep(bool asleep) {
    selectAllScreens();
    if (asleep) {
        m_tft.writecommand(TFT_DISPOFF);
        m_tft.writecommand(TFT_SLPIN);
        delay(5); // controller wants 5 ms before the next command
    } else {
        m_tft.writecommand(TFT_SLPOUT);
        delay(120); // and 120 ms after sleep-out
        m_tft.writecommand(TFT_DISPON);
    }
    reset();
    Serial.printf("Panels %s\n", asleep ? "asleep" : "awake");
}

uint8_t ScreenManager::getBrightness() {
    return m_brightness;
}

void ScreenManager::setFontColor(uint32_t color) {
    m_render.setFontColor(dim(color));
}

void ScreenManager::setFontColor(uint32_t color, uint32_t background) {
    m_render.setFontColor(dim(color));
    m_render.setBackgroundColor(dim(background));
}

void ScreenManager::setBackgroundColor(uint32_t color) {
    m_render.setBackgroundColor(dim(color));
}

void ScreenManager::setAlignment(Align align) {
    m_render.setAlignment(align);
}

void ScreenManager::setFontSize(uint32_t size) {
    m_render.setFontSize(size);
}

// Selects all screens
// I don't think that state should be used, It's kinda weird saying "ow select
// all the screens to "off"
void ScreenManager::selectAllScreens() {
    for (int i = 0; i < NUM_SCREENS; i++) {
        digitalWrite(m_screen_cs[i], LOW);
    }
}

// Unselect all screens
void ScreenManager::reset() {
    for (int i = 0; i < NUM_SCREENS; i++) {
        digitalWrite(m_screen_cs[i], HIGH);
    }
}

unsigned int ScreenManager::calculateFitFontSize(uint32_t limit_width, uint32_t limit_height, Layout layout, const String &text) {
    unsigned int calcFontSize = m_render.calculateFitFontSize(limit_width, limit_height, layout, text.c_str());
    // Serial.printf("calcFitFontSize: t=%s, w=%d, h=%d -> fs=%d\n", str, limit_width, limit_height, calcFontSize);
    return calcFontSize;
}

void ScreenManager::drawString(const String &text, int x, int y) {
    // Use current font size and alignment
    drawString(text, x, y, 0, m_render.getAlignment());
}

void ScreenManager::drawString(const String &text, int x, int y, unsigned int fontSize, Align align, int32_t fgColor, int32_t bgColor, bool applyScale) {

    if (fontSize == 0) {
        // Keep current font size
        fontSize = m_render.getFontSize();
    } else if (applyScale) {
        fontSize = getScaledFontSize(fontSize);
    }
    if (fgColor == -1) {
        // Keep current FG color
        fgColor = m_render.getFontColor();
    } else {
        fgColor = dim(fgColor);
    }
    if (bgColor == -1) {
        // Keep current BG color
        bgColor = m_render.getBackgroundColor();
    } else {
        bgColor = dim(bgColor);
    }

    // Dirty hack to correct misaligned Y
    // See https://github.com/takkaO/OpenFontRender/issues/38
    FT_BBox box = m_render.calculateBoundingBox(0, 0, fontSize, Align::TopLeft, Layout::Horizontal, text.c_str());
    m_render.setAlignment(align);
    m_render.setFontSize(fontSize);
    m_render.drawString(text.c_str(), x, y - box.yMin, fgColor, bgColor);
}

void ScreenManager::drawCenterString(const String &text, int x, int y, unsigned int fontSize) {
    drawString(text, x, y, fontSize, Align::MiddleCenter);
}
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

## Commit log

2026-08-27 ESP32-S3 SuperMini variant: what the switch actually costs
    Evaluation doc, no commitment. Pins were the question asked; they are not the
    constraint. 12 GPIO required (counted from config.h.template, not estimated),
    and the S3 SuperMini's conservative safe set is exactly 12. The C3 SuperMini
    does not fit at all.
    Two findings that change the decision:
    Retracts the flash-headroom argument. partitions.csv already maps a 4MB device
    with a 2MB app partition, so the 77.2% figure is a partition-layout constraint
    and not a chip one. An S3 with 4MB gives nothing there, and if the app
    partition needs to grow that is a one-line edit on the existing hardware.
    Upstream's PCB cannot be milled here regar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
2026-08-27 2 layers available: reverse the single-sided argument, and say what it costs
    Recorded as a reversal rather than an edit, because the reversal carries the
    information. The single-sided constraint was doing most of the arguing FOR the
    SuperMini: if every board needed a one-layer redesign anyway, the variant's PCB
    cost looked nearly free.
    With 2 layers on the table, upstream's existing KiCad project goes from
    unusable to reusable. The classic devkit then needs no PCB work at all -- send
    upstream's Gerbers -- while the SuperMini still needs a new module footprint
    and fan-out re-layout. So the variant's incremental cost went back up, and the
    case for it now rests where it always actually rested: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
2026-08-27 Layout attempt: 3-4 jumpers, and the pinout is why
    Put the geometry back into the planarity result. Pin 2 of each display
    connector carries the per-display CS and sits between two shared bus lanes --
    so every other pin resolves into a straight lane down the row while pin 2
    cannot.
    Computed rather than judged: header pads are 1.70mm on 2.54mm pitch, giving a
    0.84mm gap, and one track at the 0.40mm milling floor needs 1.20mm including
    clearance. Zero tracks fit between adjacent pads. Every CS line must therefore
    route around intervening pin columns and drop back down to pin 2, crossing the
    RST lane once each.
    Four jumpers with the module at one end, three with it mid-row. Routing RST
    above t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
2026-08-28 Correct the display rail: 3V3 off the module LDO, not 5V
    The netlist settles it -- display connector pin 7 is Net-(U1-3.3v), pin 6 GND.
    An earlier draft said the displays run off 5V VBUS, which made the regulator
    look incidental. It is not: all five hang off the module's onboard LDO.
    That makes the module comparison decisive. AMS1117-3.3 on the DevKit V1 is
    1A datasheet, ~500-600mA before thermal droop, in a SOT-223 with a real tab.
    The SuperMini carries a SOT-23-5 ME6211-class part at 500mA. Estimated peak
    demand is 550-900mA (five displays at 40-80mA plus WiFi TX bursts), which is
    marginal on the first and over the limit on the second.
    Two physical checks recorded rather than more analys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
2026-08-28 Record the KiCad lock-file and .history trap
    git add -A near an open KiCad project committed three session lock files plus
    a .history directory that is its own git repo, which lands as a gitlink
    pointing at a repo nobody else has. Caught and amended out before pushing.
    Recorded because the .history case is the nastier one: it looks like a normal
    directory and produces a clone-breaking reference rather than an obvious
    mistake.
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2026-08-28 ESPHome: right instinct, blocked by its framebuffer model
    ESPHome supports GC9A01A via ili9xxx, and would supply OTA, a web server and
    secrets.yaml as components rather than as work -- plus the bigger prize of
    sourcing data from Home Assistant and retiring the API keys entirely.
    It does not fit. The ili9xxx component allocates a full framebuffer per
    display; an open feature request for partial buffering confirms that is current
    behaviour. Measured against our own build's DRAM report rather than a datasheet:
    327,680 B budget, 53,084 B already used, 274,596 B free. Five 240x240 buffers
    need 576,000 B at 16-bit and 288,000 B at 8-bit. Both exceed all free DRAM
    before ESPHome's runtime or the W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
2026-08-28 Record the strapping-pin pattern on user-facing connections
    Two independent boards for this project put a strapping pin where a user can
    drive it: upstream exposes GPIO12 (MTDI, flash voltage select) on the U1 sensor
    header two pins from 3V3, and HackerBox 0129 assigns GPIO3 (S3 JTAG source) to
    BUTTON_RIGHT with buttons wired to VCC.
    Same signature both times -- an intermittent no-boot that only occurs when
    something is held at reset, which is why nobody traces it to the button.
    Also records why porting a pin map between ESP32 variants is hazardous: the
    strapping set differs (classic 0/2/5/12/15, S3 0/3/45/46), so a map that was
    safe on one silently becomes unsafe on the other.
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2026-08-29 Yang's KiCad 10 board, with libraries made project-local
    Yang's note said to move the symbols and footprints "wherever you keep your
    custom libraries". Doing that would reproduce exactly the failure this repo
    already documents in upstream's board, which references "A Local Libs" and
    "New folder" -- libraries that exist on one machine, leaving footprints that
    render from the board's cache but cannot be placed or updated by anyone else.
    So they go in lib/ instead, wired through sym-lib-table and fp-lib-table with
    ${KIPRJMOD}. Clone, open, done. Verified: all five library nicknames the
    schematic and board reference now resolve to files that exist.
    The zip was missing _Logos, which the board p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
    [hot_info_orbs.kicad_pcb, hot_info_orbs.kicad_sch]
2026-08-29 Board fixes: DS5 DC connected, button off the strapping pin, GND pour added
    Three changes to Yang's Rev 1.0, all verified against the file and by re-running
    KiCad's own checks -- ERC 0, DRC 0, 0 unconnected pads, 0 schematic parity
    issues, and the three silkscreen warnings cleared too.
    DS5 pin 5 (DC) now lands on Net-(DS1-DC). The wire had been drawn but stopped
    3.81mm short of the pin, so the fifth display had no data/command line. Worth
    noting DRC could never have caught it: the board faithfully implemented the
    schematic, and the gap was in the schematic. Only ERC sees that class.
    SW3 moved from GPIO3 to GPIO10. GPIO3 is an ESP32-S3 strapping pin and the
    buttons pull high, so holding tha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
    [hot_info_orbs.kicad_pcb, hot_info_orbs.kicad_sch]
2026-08-29 Fab package for JLCPCB, ready to upload
    Gerbers and Excellon drill generated from the board with kicad-cli, zipped for
    upload. Restricted to the seven layers a bare board needs -- KiCad's default
    export also emits Courtyard, Fab, Adhesive, Paste and User_1-9, none of which
    JLCPCB uses and any of which can trigger a query.
    Committed rather than left as a one-off export so the files actually ordered
    from are recorded. If a board comes back wrong, the question is what was sent,
    and an export sitting in someone's Downloads cannot answer it.
    fab/README.md records the regeneration command, the order parameters, and the
    expected drill-tool table: 21 vias at 0.30, 2 at 0.80, 53 at 1.00, 12 at 1.10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
    [hot_info_orbs-B_Cu.gbl, hot_info_orbs-B_Mask.gbs, hot_info_orbs-B_Silkscreen.gbo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]
2026-08-29 Put JLCPCB's design rules in; DRC was checking nothing before
    Every constraint was 0.0, so a clean DRC meant only that nothing was
    overlapping. Now set from JLC's published standard 2-layer figures: 0.10mm
    track and clearance, 0.15mm drill, 0.25mm via. Board uses 0.2 and 0.35mm
    tracks, so 2-3.5x margin. DRC clean at those values.
    Annular width is set to 0.15 rather than the 0.18 JLC's page states, and the
    reasoning is recorded in fab/README rather than buried here: that page's
    numbers are not internally consistent (0.15mm min drill and 0.25mm min via
    cannot both hold with a 0.18mm ring), and 0.6/0.3 is KiCad's default via,
    fabricated at JLC constantly. Flagged as the one number worth confir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
2026-08-29 Yang's v2: near-complete reroute, DS5 fixed, real logo library, 3D models
    Second board from Yang, received while we were fixing the first. He reworked
    the routing substantially -- 192 of 211 track segments removed and 197 added,
    against 19 segments in common with our version -- and moved signal copper onto
    F.Cu, dropping B.Cu from 309mm to 221mm. That leaves the back layer clearer
    than v1 did, which suits the ground pour better than his original would have.
    He fixed DS5's DC pin independently. He did not move the button off GPIO3 and
    did not add a pour, so those two of our three changes still need re-applying
    on top of this; that is the next commit rather than this one, so his work and
    ours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
    [hot_info_orbs.kicad_pcb, hot_info_orbs.kicad_sch]
2026-08-29 Re-apply our changes onto Yang's v2, and drop the now-stale fab package
    Onto his board: GND pour on B.Cu, a B.Cu antenna keepout, both keepouts set to
    copperpour not_allowed, and the JLCPCB design rules his .kicad_pro had back at
    0.0 clearance and track width.
    I got the keepout wrong first and it is worth recording why. I transplanted the
    B.Cu keepout from our earlier board, which put it 18mm from the antenna, and
    DRC duly reported one of Yang's +5V tracks as forbidden copper. The track was
    fine; my keepout was in the wrong place.
    The cause is the interesting part: **Yang rotated and moved the module in v2**,
    from (131.06, 91.17) at rot=180 to (131.10, 95.89) at rot=0. He moved his F.Cu
    ke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
    [hot_info_orbs-B_Cu.gbl, hot_info_orbs-B_Mask.gbs, hot_info_orbs-B_Silkscreen.gbo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]
2026-08-29 v1.1 first production run: SW3 to GPIO10, pour filled, gerbers generated
    Board is Yang's v1.1 with the three changes settled: SW3 moved off GPIO3, which
    is an ESP32-S3 strapping pin the buttons would have driven high at reset;
    GPIO3 now unconnected and GPIO10 carries the button. GND pour on B.Cu, filled.
    Antenna keepout mirrored onto B.Cu and both layers set to block copper fill --
    his original was F.Cu only and allowed the pour, which would have flooded copper
    under the antenna the keepout exists to protect. Yang's leftover 3.81mm wire
    stub from his own DS5 fix is gone.
    Verified rather than assumed: ERC 0, DRC 0 unconnected pads, 0 schematic parity
    issues. One silkscreen overlap on B.Silks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
    [hot_info_orbs-B_Cu.gbl, hot_info_orbs-B_Mask.gbs, hot_info_orbs-B_Silkscreen.gbo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]
2026-08-29 Via geometry resolved: JLC's order form measures diameter, not annular ring
    The 0.6/0.3 vias were flagged against a "0.18mm minimum annular ring" figure
    from JLCPCB's capabilities page. Wrong number. Their order form states the rule
    as a diameter difference: "Via diameter should be 0.1mm (0.15mm preferred)
    larger than Via hole size." For a 0.3mm hole that is 0.4mm minimum, 0.45mm
    preferred -- and these are 0.6mm, three times the minimum.
    Also confirms no surcharge: "No additional charge when the via hole >=0.3mm,
    and via diameter >=0.4mm." Both met exactly.
    So the last open question on this run is closed in the board's favour, and the
    caveat is removed from fab/README rather than left to w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
2026-08-29 README: our project, with upstream credited properly
    Replaces Brett's README, which described his hardware, his wiring, his dev kit
    and a config flow this repo no longer uses. Keeping it meant the first thing
    anyone read was instructions for a board we do not build.
    Credit is more prominent than it was, not less: upstream is named in the second
    section with links to his repository, his contributors, his assembly video and
    his dev kit, and it says plainly that the firmware is his and only the board is
    ours. AGPL-3.0 and LICENSE.txt unchanged, with a line explaining what the
    licence actually obliges when a built board is handed to someone.
    Leads with what differs from upstream, because that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
2026-09-10 Route Serial to USB on the S3; the monitor was attaching to nothing
    The port was ported but the serial path was not. Arduino's Serial defaults to
    UART0 on GPIO43/44, so on a board whose only connector is the MCU's own USB, the
    monitor attached to a device with no CDC endpoint behind it -- connecting,
    printing nothing, and dropping in a loop.
    Adds ARDUINO_USB_MODE=1 and ARDUINO_USB_CDC_ON_BOOT=1.
    Recorded in TRAPS with the diagnostic that matters more than the fix: the
    symptom is indistinguishable from a boot loop, and 20 pings at 0% loss
    distinguishes them in ten seconds. Here the firmware had been running correctly
    on the network throughout, and the temptation was to go looking for a cras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
2026-09-10 Revert the USB CDC flags: they make the board vanish from the host
    Adding ARDUINO_USB_MODE=1 and ARDUINO_USB_CDC_ON_BOOT=1 was supposed to route
    Serial to the USB port. On this board it does something worse than not working:
    the application claims the USB peripheral instead of leaving it to the ROM,
    fails to enumerate, and the device disappears from the host entirely -- no
    /dev/cu.usbmodem*, nothing in system_profiler. The firmware runs fine throughout
    and stays on WiFi answering pings; there is just no port left to flash over, and
    recovery needs manual bootloader entry.
    Flags removed, with a warning left in their place in platformio.ini so the next
    person does not reach for the obvious fix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
2026-09-10 Correct the inrush: 1.15 A measured, not clipped
    The first write-up recorded boot inrush as ">1 A, clipped", on my assumption
    that the PPK II source meter limits at 1 A. It does not -- a second capture read
    the peak directly at 1.15 A.
    Second window also shows the boot profile rather than just a number: a single
    narrow spike at power-on, settling to ~240 mA, stepping through ~270 and ~300 mA
    as the five display regulators come up in sequence, then ~340 mA once the radio
    joins.
    Sharpens the supply advice from a hedge to a figure. 1.15 A is 3.4x the running
    current, so a supply chosen for the 342 mA average WILL sag at power-on -- and
    the resulting fault, an orb that starts on one charger bu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
2026-09-23 OTA updates (R2): browser upload + ArduinoOTA, two-slot partitions
    Browser page at http://info-orbs.local/update for people without a
    toolchain; `pio run -e ota -t upload` for people with one. Optional
    OTA_PASSWORD in secrets.h guards both.
    Partitions: two 1.875 MB app slots, app at 83.4%. The filesystem went
    from 1.9 MB to 128 KB rather than squeezing the slots: only
    WebDataWidget's image cache uses it and nothing calls LittleFS.begin().
    Rollback: the prebuilt bootloader has it on, but the core marks a new
    image valid before setup(). verifyRollbackLater() now defers that to
    after WiFi is up and OTA is listening, so an image that cannot take the
    next update is reverted on its next reset. R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
    [partitions.csv]
2026-09-23 OTA tested on hardware: update over WiFi lands in app1 and confirms itself
    Measured, not inferred: otadata read back over USB shows seq 2 / VALID.
    Also records that curl to info-orbs.local stalled while the IP answered.
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2026-09-23 settings: NVS store, and every v1 setting read through it
    Settings (Preferences namespace "orbs") holds the 15 v1 values; a key never
    saved falls back to its config.h macro, so an orb that never opened the page
    runs exactly as built. Loaded first in setup(), before anything reads it.
    Read sites switched: invert (ScreenManager), night dim (WidgetSet - now a
    runtime if, level still DIM_BRIGHTNESS or 128), 24h and metric date and the
    timezone (GlobalTime), colours, face, 24h and AM/PM (ClockWidget), location,
    units and dark mode (WeatherWidget), tickers (StockWidget), rotation (main).
    Fixed on the way through:
    - StockWidget wrote m_stocks[5] before its bound check broke the loop.
    The check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
    [GlobalTime.cpp, ScreenManager.cpp, StockWidget.cpp]
2026-09-23 settings: the /settings page - form, save-and-restart, reset
    GET /settings shows every v1 field with its current value and the config.h
    default beside it; POST validates every field, and on any error re-renders
    with the message at the field and saves nothing. On success it writes NVS
    and restarts. POST /settings/reset clears the namespace and restarts.
    "/" redirects to /settings.
    A field that is not sent keeps its current value, so `curl -d cycle=20`
    changes one setting. Booleans are selects posting 0/1 rather than
    checkboxes, because an unticked checkbox sends nothing and would be
    indistinguishable from "not sent".
    Shares OtaUpdater's server and password: OtaUpdater gains server() and
    aut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
    [OtaUpdater.cpp, main.cpp]
2026-09-24 settings: user-uploadable boot picture on screen 2
    The page takes any photo, centre-crops it to 240x240 on a canvas, previews
    it in a circle and uploads canvas.toBlob('image/jpeg'), stepping quality
    down from 0.85 until it is at most 64 KB. The browser does the encoding
    because toBlob always writes baseline JPEG, the only kind TJpg_Decoder
    draws. Rejected: decoding and scaling a phone photo on the orb - no PSRAM,
    and a 4000x3000 JPEG does not fit the heap.
    The orb does not trust the browser: the upload streams to /boot.tmp (64 KB
    cap), the first 4 KB go through sv::checkJpegHeader, and only then is it
    renamed over /boot.jpg - an interrupted upload never replaces the picture.
    At boot, a sto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
    [main.cpp]
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2026-09-24 Weather: fetching moves behind WeatherSource; Visual Crossing moved as is
    No behaviour change. WeatherWidget keeps all drawing and the retry /
    10-minute logic and calls m_source->fetch(model). VisualCrossingSource is
    the old getWeatherData() body verbatim, URL built from Settings as before.
    Flash +460 bytes (1,709,685 -> 1,710,145), 87.0%.
    Rejected a separate Tempest widget (approach B in the spec): it would copy
    ~400 lines of drawing code, costing flash and making every fix twice.
    The widget owns and deletes its source. WidgetSet never deletes widgets
    today, but the destructor is then correct if it ever does.
    [VisualCrossingSource.cpp, main.cpp]
2026-09-24 Tempest: one weather page per station, settings rows with last-fetch status
    TempestSource streams better_forecast with useHTTP10 + a filter on the
    stream, never the ~96 KB body, since the SuperMini has no PSRAM. The station
    rows on /settings show the last fetch per station (tick or cross, time,
    duration, free heap, error), because there is no serial on this board.
    Flash: no token 1,710,645 (+500 over the split, the two extra string fields
    in a struct copied by value); with token 1,728,241, 87.9%. Stop line 92%.
    The Tempest NVS keys are compiled out without a token too: left in, they
    cost 1.3 KB on a build that can never use them.
    The token stays in secrets.h and is not on the page. Putting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
    [main.cpp]
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2026-09-24 Boot screen: show flash used against one OTA slot under Welcome
    Read from the running image (ESP.getSketchSize / getFreeSketchSpace), so it is
    always the firmware that is actually running, not a build-time number that can
    drift. Orb 0 rather than under the version on orb 1: orb 1's remaining chord at
    that height is too narrow for a second line. No colour warning near the 92%
    stop line; it is a developer figure, not an alarm for club members.
    +304 bytes (1,709,685 -> 1,709,989).
    [main.cpp]
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2026-09-24 Show: tick which pages rotate; one ticked = a static display
    Scott, 2026-09-24: "each panel set with a check box, pick 1 or as many as
    you want". Stored as the names NOT shown (key "hidden"), so a widget added
    by a later build shows up by default instead of silently staying off. With
    one page ticked, next/prev and auto-cycle do nothing, so a static page
    never redraws every cycle. Hidden widgets never fetch. If every stored
    name is hidden (e.g. renamed), all show rather than a blank orb.
    Rejected: a single "start on" page plus cycle=0. It pins one page but
    cannot rotate through a subset, which the checkboxes do for free.
    Also fixes upstream's updateAll(): its loop counter was uninitialised.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
    [main.cpp]
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2026-09-24 OTA status screen: use the default font, not the current widget's
    Scott: on the nixie clock the 'Updating' / percent text was illegible.
    drawStatus never set a font, so it drew in whatever the showing widget last
    set - on the clock, DSEG, which has almost no letters. Set it in drawStatus
    rather than restoring it afterwards: every widget sets its own font at the
    top of draw(), so nothing leaks back.
    [OtaUpdater.cpp]
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2026-09-25 Backlight test route: /bltest sends GC9A01 53h/51h to all panels
    For the dark-room check of the LEDPWM pin found in datasheet 5.10.3. On
    tempest only, not main: a throwaway probe, removed once answered. Behind the
    /update password. Undo is a restart, not a 'restore' command, because the
    reset state (LEDPWM Low) is the one the orbs normally run in.
    [OtaUpdater.cpp, ScreenManager.cpp]
2026-09-25 US spelling across the project: color, center, authorize, normalize...
    Scott: the project uses US English. Identifiers too (drawCenterString,
    parseHexColor, normalizeText, authorized()), since this fork no longer
    merges upstream and mixed spellings make grep miss half the hits.
    Left alone on purpose: TFT_eSPI's own names (TFT_LIGHTGREY, TFT_DARKGREY),
    vendored libraries, and the "grey"/"darkgrey" colour names the web-data
    parser accepts - existing JSON uses them, so 'gray' is added as an alias
    instead of replacing them. NVS keys had no British spellings, so stored
    settings are unaffected.
    [MQTTWidget.cpp, OtaUpdater.cpp, ScreenManager.cpp]
2026-09-25 WiFi: join the strongest AP and roam off a weak one
    An orb moved across the building stayed on its far AP (341 ms ping, 5% loss,
    every 96 KB Tempest reply truncated) and a restart put it back there: the
    default fast scan takes the first AP heard. Now: all-channel scan sorted by
    signal at connect, and while connected a background scan below -65 dBm that
    moves to an AP >= 8 dB stronger, falling back to a name-only rejoin after 20 s.
    Settings page shows dBm (with a glyph), AP and channel.
    Rejected: relying on UniFi band/AP steering or lock-to-AP (per-device, owner
    has to know, not everyone runs UniFi) and 802.11k/v/r (needs router support
    and IDF options this Arduino build doesn't expose).
    Co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
    [WifiWidget.cpp, main.cpp]
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2026-09-25 Flash 89.0% -> 85.0%: drop unused FinalFrontier, re-save nixie + logo at q80
    FinalFrontier (19.8 KB) was embedded but no widget selects it; kept behind
    USE_FINAL_FRONTIER rather than deleted, upstream-style, so the config
    template's option still has a path. Nixie digits and logo re-saved with PIL
    at quality 80, original chroma subsampling kept, baseline (TJpgDec can't do
    progressive): -57.7 KB. Weather icons skipped (already ~q80, -3 KB) and the
    custom clock placeholders too (-1 byte each). Rejected for now: font
    subsetting, which needs fonttools and a license check.
    [ScreenManager.cpp]
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
